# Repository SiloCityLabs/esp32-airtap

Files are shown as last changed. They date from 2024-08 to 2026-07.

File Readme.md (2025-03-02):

# AC Infinity ESP32 Mods



This repository contains code and instructions to modify the AC Infinity products with an ESP32 microcontroller. The ESP32 is a powerful microcontroller that can be used to control the fan speed, monitor temperature and humidity, and connect to the internet. The modifications described in this repository will allow you to control your fan remotely, set up schedules, and monitor environmental conditions in your grow room or other indoor space.

Get it on [SiloCityLabs Shop](https://shop.silocitylabs.com/products/esp32-module-for-ac-infinity-airtap-t4-t6)

 ## Airtap T-Series ESP32 Mods

Code and instructions to modify the AC Infinity Airtap T-Series inline duct fans with an ESP32 microcontroller.

**Youtube Video:** [Shorts](https://www.youtube.com/shorts/T40RKEEfJKI)

 - Disassembly: Carefully open your AC Infinity vent to access the original PCB.
 - Compare PCB Layout: Match your vent’s PCB layout with the images provided to ensure compatibility with one of the three supported versions.
 - Upload Firmware: Use the provided ESPHome configuration links to upload the correct firmware version to your ESP32 module or alternative firmware compatible with ESP32-c3 module.
 - Install the ESP32 Module:
 - Replace the existing PCB with the ESP32 module.
 - Connect the PWM fans and NTC thermistor to the corresponding terminals on the new PCB.
 - (If needed) Solder the power cable to the correct pads on the PCB.
 - Secure the Module: Reassemble the vent, ensuring that all connections are secure and the module is properly seated.
 - Test Functionality: Power on the vent and check that the display is working and the device connects to your Wi-Fi network.

### How to identify your Generation

3 buttons is Gen 1, 4 buttons is Gen 2.

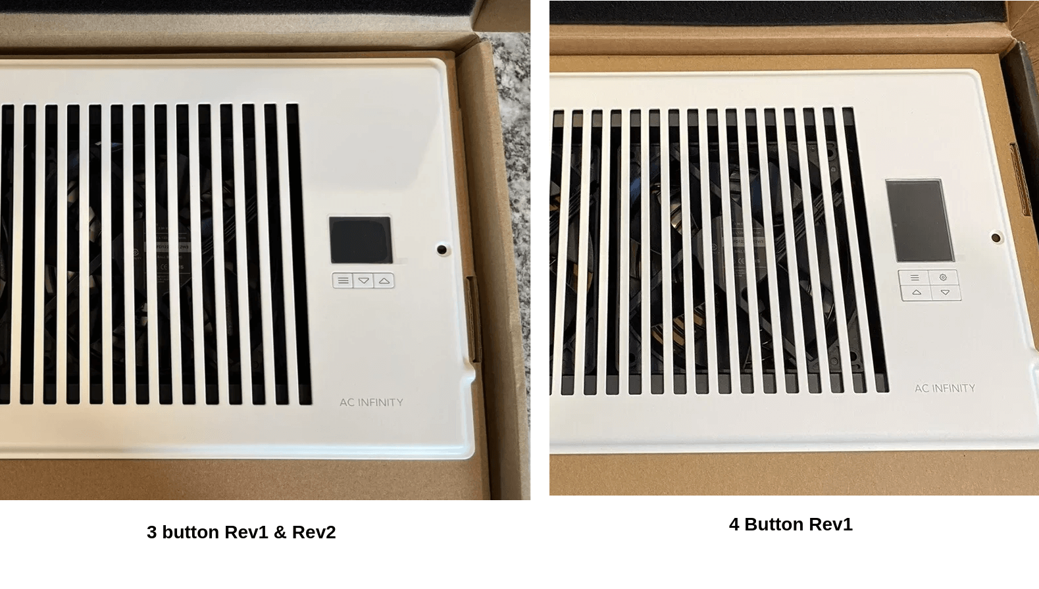
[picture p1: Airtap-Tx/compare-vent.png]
Vent Comparison


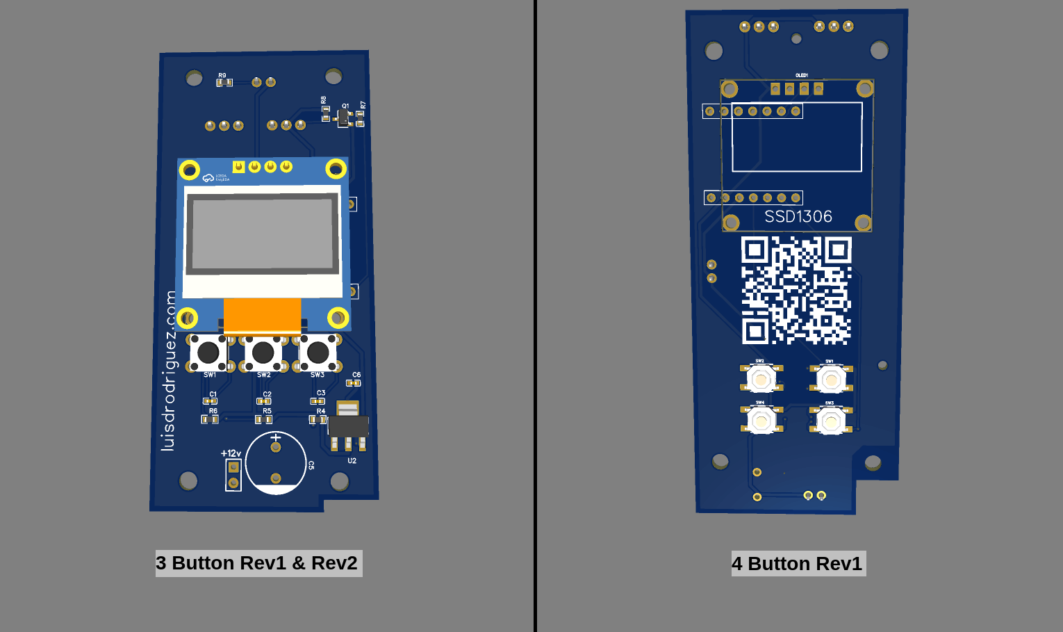
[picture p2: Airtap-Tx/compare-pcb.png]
PCB Comparison


### Gen 1 Rev 1

This revision of Gen 1 has an aligment issue. When installed you should only use two left screws to secure the PCB. The right screws will not align with the holes. Also includes individual fan control with two PWM outputs.

[ESPHome Configuration](Airtap-Tx/Gen-1/esphome-3btn-rev1.yaml)

This includes a font that needs to be downloaded and placed in the same directory as your configuration file. You can download the font file [here](https://font.download/font/arial)

#### Pinout:

| ESP32 Pin | Function | Xiao Pin |
|---|---|---|
| GPIO2 | PWM | D0 |
| GPIO3 | PWM | D1 |
| GPIO4 | Temp | D3 |
| GPIO6 | OLED SDA | D4 |
| GPIO7 | OLED SCL | D5 |
| GPIO8 | Button Up | D8 |
| GPIO9 | Button Down | D9 |
| GPIO10 | Button Toggle | D10 |

#### Features
 - 2x PWM Output
 - 1x Temperature Sensor
 - 1x Display
 - 3x Button

### Gen 1 Rev 2

This is the second revision of Gen 1. It has the same layout with fixed hole aligment. The second PWM output was removed and both fans are controlled from a single PWM output.

[ESPHome Configuration](Airtap-Tx/Gen-1/esphome-3btn-rev2.yaml)

This includes a font that needs to be downloaded and placed in the same directory as your configuration file. You can download the font file [here](https://font.download/font/arial)

#### Features
 - 1x PWM Output
 - 1x Temperature Sensor
 - 1x Display
 - 3x Button

#### Pinout:

| ESP32 Pin | Function | Xiao Pin |
|---|---|---|
| GPIO2 | PWM | D0 |
| GPIO4 | Temp | D3 |
| GPIO6 | OLED SDA | D4 |
| GPIO7 | OLED SCL | D5 |
| GPIO8 | Button Up | D8 |
| GPIO9 | Button Down | D9 |
| GPIO10 | Button Toggle | D10 |

### Gen 2 Rev 1

This is the second Generation of Airtap series. AC Infinity introduced a larger display, 4 buttons, bluetooth and a new PCB layout. This revision has a single PWM output and a temperature sensor.

[ESPHome Configuration](Airtap-Tx/Gen-2/esphome-4btn-rev1.yaml)

#### Features
 - 1x PWM Output
 - 1x Temperature Sensor
 - 1x Display
 - 4x Button

#### Pinout:

| ESP32 Pin | Function | Xiao Pin |
|---|---|---|
| GPIO2 | PWM | D0 |
| GPIO4 | Temp | D3 |
| GPIO6 | OLED SDA | D4 |
| GPIO7 | OLED SCL | D5 |
| GPIO20 | Button Up | D7 |
| GPIO8 | Button Down | D8 |
| GPIO9 | Button Toggle | D9 |
| GPIO10 | Button Menu | D10 |

 ## Availability
You can get the assembled boards in my [Shop](https://shop.silocitylabs.com/products/esp32-module-for-ac-infinity-airtap-t4-t6)

## Certifications

This project is certified by the [Open Source Hardware Association (OSHWA)](https://certification.oshwa.org/us002672.html)

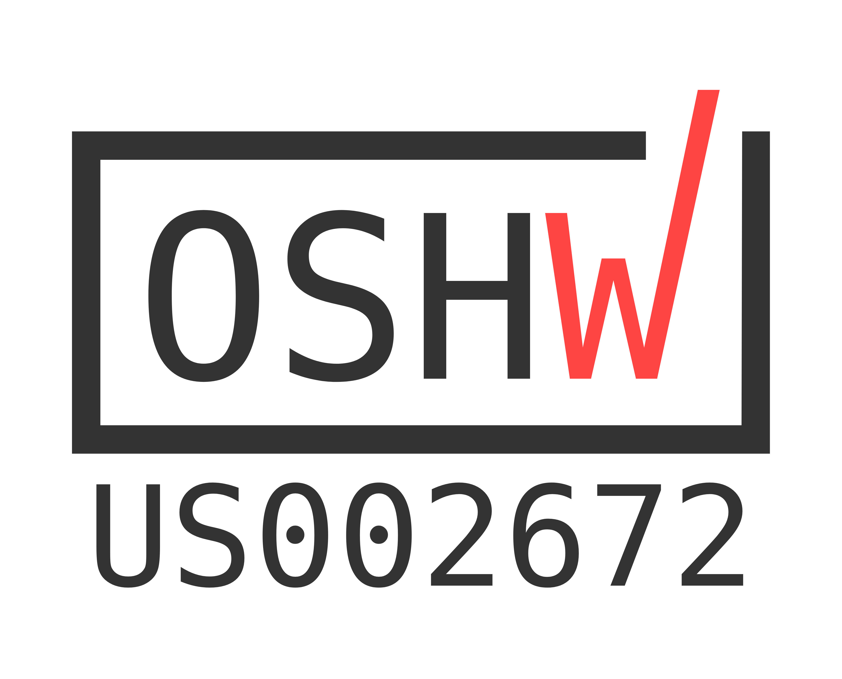
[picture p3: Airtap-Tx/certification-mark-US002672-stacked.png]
Open Source Hardware Association Certification


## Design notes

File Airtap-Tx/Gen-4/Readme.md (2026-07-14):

This is a new Airtap by AC Infinity. Reverse engineering notes here:

Header Pads exposed:
 - IO9 (BOOT / download strap — hold LOW + pulse EN to enter ROM bootloader)
 - GND
 - TX
 - RX
 - 3.3V
 - EN

Chip: ESP32-C6-WROOM-1
UART console: 115200 8N1 on TX/RX header

OEM boot log (normal SPI boot):
- Project: smarthome_device_airtap v2.1 (ESP-IDF v5.4.1, Apr 9 2026 20:33:54)
- Versions reported: hw 3.0 / sw 3.0.15
- Secure boot: RSA-PSS enabled (verification succeeded)
- Flash encryption: DEVELOPMENT (not secure)
- Power-on path: BLE / Blufi provisioning
- MAC seen: a0:f2:62:71:bc:e4
- Input GPIOs (pull-up): 5, 6, 7, 21, 22
- Output GPIOs: 8, 10, 11, 15, 18, 19, 23, 20, 1, 4

Download mode (UART dump/flash):
1. Hold IO9 to GND
2. Pulse EN low then high
3. Release IO9
4. esptool --port /dev/ttyUSB0 --chip esp32c6 --before no-reset --after no-reset ...
   Use baud <= 460800 on this CH340; 921600 corrupts the link.

Flash dump:
- oem-firmware-full.bin — full 8MB SPI dump (ciphertext; flash encryption enabled)
- SHA256: ff35eccd4f6936a8b0c3f98f9bc9d93c65edfefdc661ccb78f1077a39ab8743d
- oem-partition-table.bin — 0x8000..0x8C00 (also ciphertext)
- oem-security-info.txt / oem-efuse-summary.txt
- Flash size: 8MB (GD/c8 4017)
- SPI_BOOT_CRYPT_CNT=0b111 (encryption permanently on)
- RD_DIS blocks reading KEY0/KEY1 (flash encrypt key not readable via espefuse)
- Secure boot digests present; JTAG permanently disabled; DIS_DOWNLOAD_ICACHE=1
- DIS_DOWNLOAD_MANUAL_ENCRYPT=0 (download-mode encrypt still allowed)

Manual Pin traces:

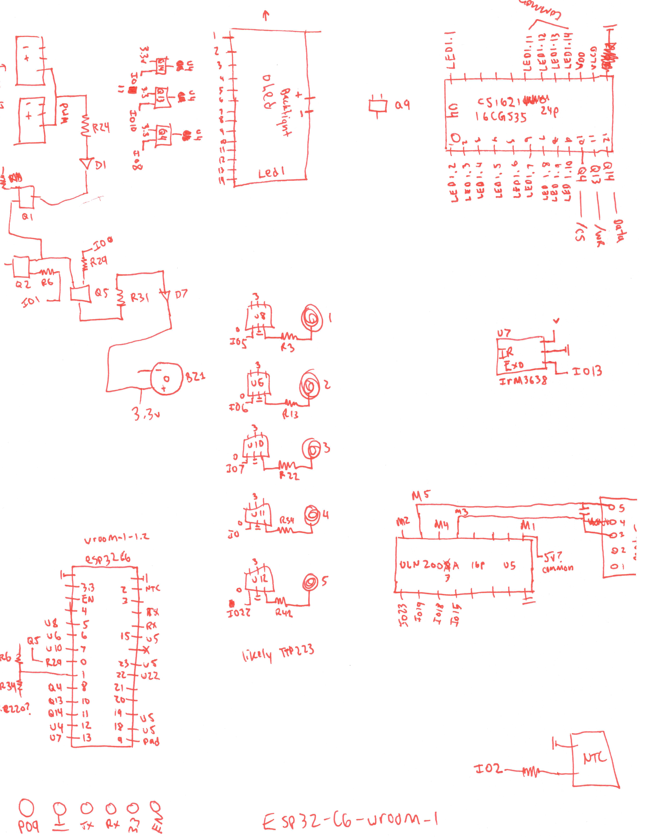
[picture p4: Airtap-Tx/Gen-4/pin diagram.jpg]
Pin diagram


| GPIO | Chip / target | Notes |
| --- | --- | --- |
| IO0 | Piezo (BZ1) via Q5 | R29 → Q5; likely buzzer drive |
| IO1 | Fan PWM / power via Q2 | R6/R34 → Q2; PWM path TBD vs Q1 |
| IO2 | NTC | ADC / temp sense |
| IO3 | — | Untraced |
| IO4 | — | Untraced |
| IO5 | TTP223 (U8) | Touch 1 |
| IO6 | TTP223 (U6) | Touch 2 |
| IO7 | TTP223 (U10) | Touch 3 |
| IO8 | CS1621 via Q4 | `/CS` |
| IO9 | Header pad | BOOT / download strap |
| IO10 | CS1621 via Q13 | `/WR` |
| IO11 | CS1621 via Q14 | `DATA` |
| IO12 | — | Untraced |
| IO13 | IRM3638 | IR receiver |
| IO15 | ULN2003A | Motor pin 4 |
| IO18 | ULN2003A | Motor pin 3 |
| IO19 | ULN2003A | Motor pin 2 |
| IO20 | — | Untraced (backlight candidate?) |
| IO21 | TTP223 | Touch 4 (hard to probe; firmware input) |
| IO22 | TTP223 (U12) | Touch 5 |
| IO23 | ULN2003A | Motor pin 1 |

Still missing pin matching:

PWM Control, Likely one of Q1, Q2 or Q5 Transistors
Piezzo Likely Q2 or Q5 transistors
Backlight?

CS1621:

| Pin | Signal |
| --- | --- |
| 1 | LED 1.2 |
| 2 | LED 1.3 |
| 3 | LED 1.4 |
| 4 | LED 1.5 |
| 5 | LED 1.6 |
| 6 | LED 1.7 |
| 7 | LED 1.8 |
| 8 | LED 1.9 |
| 9 | LED 1.10 |
| 10 | /CS |
| 11 | /WR |
| 12 | DATA |
| 13 | GND |
| 14 | VLCD ? |
| 15 | VDD |
| 16 | LED 1.14 |
| 17 | LED 1.13 |
| 18 | LED 1.12 |
| 19 | LED 1.11 |
| 20 | NC |
| 21 | NC |
| 22 | NC |
| 23 | NC |
| 24 | LED 1.1 |

Serial log confirmation (2026-07-13 capture → serial-logs/latest.log):
GPIO init vs traces:
- Confirmed inputs (pull-up): IO5/6/7/21/22 → matches TTP223 on 5/6/7/22; IO21 still unknown but is a 5th touch/key input in firmware
- Confirmed outputs: IO8/10/11 → matches CS1621 /CS /WR DATA
- Confirmed outputs: IO15/18/19/23 → matches ULN2003A motor pins
- IO2: neither in nor out (ADC-style) + Curve Fitting calibration immediately after → supports NTC on IO2
- Confirmed outputs still ambiguous: IO1, IO4, IO20 (buzzer / PWM / backlight candidates)
- IO0 never appears in gpio init log (may still be buzzer path, just not logged here)
- RMT RX channel enabled → supports IR RX (IRM3638 / IO13); pin number not printed
Runtime interaction in same capture:
- ct_ir_manage power 0→1 (IR remote power)
- Key_Func "Up Key" twice → ipcd_set_speed 2 then 3

Custom firmware / pinprobe:
- esphome-pinprobe.yaml cycles GPIO0(PWM) / 1(2kHz) / 4(4kHz) / 20 / 3 / 12
- FLASHED 2026-07-13 with --encrypt: write succeeded, boot FAILED
  - "Image not V2 signed?" / "RSA-PSS secure boot verification failed" bootloop
- OEM restored via firmware-dump/oem-firmware-full.bin (hash verified)
- End-goal ESPHome on THIS module is blocked without AC Infinity signing key
- Path forward: replace ESP32-C6-WROOM-1 with an unlocked module, then flash ESPHome

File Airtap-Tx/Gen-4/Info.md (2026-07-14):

This is a new Airtap by AC Infinity. Reverse engineering notes here:

Header Pads exposed:
 - IO9 (BOOT / download strap — hold LOW + pulse EN to enter ROM bootloader)
 - GND
 - TX
 - RX
 - 3.3V
 - EN

Chip: ESP32-C6-WROOM-1
UART console: 115200 8N1 on TX/RX header

OEM boot log (normal SPI boot):
- Project: smarthome_device_airtap v2.1 (ESP-IDF v5.4.1, Apr 9 2026 20:33:54)
- Versions reported: hw 3.0 / sw 3.0.15
- Secure boot: RSA-PSS enabled (verification succeeded)
- Flash encryption: DEVELOPMENT (not secure)
- Power-on path: BLE / Blufi provisioning
- MAC seen: a0:f2:62:71:bc:e4
- Input GPIOs (pull-up): 5, 6, 7, 21, 22
- Output GPIOs: 8, 10, 11, 15, 18, 19, 23, 20, 1, 4

Download mode (UART dump/flash):
1. Hold IO9 to GND
2. Pulse EN low then high
3. Release IO9
4. esptool --port /dev/ttyUSB0 --chip esp32c6 --before no-reset --after no-reset ...
   Use baud <= 460800 on this CH340; 921600 corrupts the link.

Flash dump:
- oem-firmware-full.bin — full 8MB SPI dump (ciphertext; flash encryption enabled)
- SHA256: ff35eccd4f6936a8b0c3f98f9bc9d93c65edfefdc661ccb78f1077a39ab8743d
- oem-partition-table.bin — 0x8000..0x8C00 (also ciphertext)
- oem-security-info.txt / oem-efuse-summary.txt
- Flash size: 8MB (GD/c8 4017)
- SPI_BOOT_CRYPT_CNT=0b111 (encryption permanently on)
- RD_DIS blocks reading KEY0/KEY1 (flash encrypt key not readable via espefuse)
- Secure boot digests present; JTAG permanently disabled; DIS_DOWNLOAD_ICACHE=1
- DIS_DOWNLOAD_MANUAL_ENCRYPT=0 (download-mode encrypt still allowed)

Manual Pin traces:

IO0 - R29 -> Q5 -> ?? Maybe Buzzer
IO1 - R6/R34 -> ??
IO2 - NTC
IO3 - ??
IO4 - ??
IO5 - TTP223 TOUCH 1
IO6 - TTP223 TOUCH 2
IO7 - TTP223 TOUCH 3
IO8 - Q4(Transistor) -> CS1621(/CS)
IO9 - PAD9
IO10 - Q13(Transistor) -> CS1621(/WR)
IO11 - Q14(Transistor) -> CS1621(DATA)
IO12 - ??
IO13 - IRM3638 IR
IO15 - Motor Pin 4 (ULN2003A)
IO18 - Motor Pin 3 (ULN2003A)
IO19 - Motor Pin 2 (ULN2003A)
IO20 - ??
IO21 - TTP223 TOUCH 4
IO22 - TTP223 TOUCH 5
IO23 - Motor Pin 1 (ULN2003A)

Still missing pin matching:

PWM Control, Likely one of Q1, Q2 or Q5 Transistors
Piezzo Likely Q2 or Q5 transistors
Backlight?

CS1621:

1 - LED 1.2
2 - LED 1.3
3 - LED 1.4
4 - LED 1.5
5 - LED 1.6
6 - LED 1.7
7 - LED 1.8
8 - LED 1.9
9 - LED 1.10
10 - /CS
11 - /WR
12 - DATA
13 - GND
14 - VLCD ?
15 - VDD
16 - LED 1.14
17 - LED 1.13
18 - LED 1.12
19 - LED 1.11
20 - NC
21 - NC
22 - NC
23 - NC
24 - LED 1.1

Serial log confirmation (2026-07-13 capture → serial-logs/latest.log):
GPIO init vs traces:
- Confirmed inputs (pull-up): IO5/6/7/21/22 → matches TTP223 on 5/6/7/22; IO21 still unknown but is a 5th touch/key input in firmware
- Confirmed outputs: IO8/10/11 → matches CS1621 /CS /WR DATA
- Confirmed outputs: IO15/18/19/23 → matches ULN2003A motor pins
- IO2: neither in nor out (ADC-style) + Curve Fitting calibration immediately after → supports NTC on IO2
- Confirmed outputs still ambiguous: IO1, IO4, IO20 (buzzer / PWM / backlight candidates)
- IO0 never appears in gpio init log (may still be buzzer path, just not logged here)
- RMT RX channel enabled → supports IR RX (IRM3638 / IO13); pin number not printed
Runtime interaction in same capture:
- ct_ir_manage power 0→1 (IR remote power)
- Key_Func "Up Key" twice → ipcd_set_speed 2 then 3

Custom firmware / pinprobe:
- esphome-pinprobe.yaml cycles GPIO0(PWM) / 1(2kHz) / 4(4kHz) / 20 / 3 / 12
- FLASHED 2026-07-13 with --encrypt: write succeeded, boot FAILED
  - "Image not V2 signed?" / "RSA-PSS secure boot verification failed" bootloop
- OEM restored via firmware-dump/oem-firmware-full.bin (hash verified)
- End-goal ESPHome on THIS module is blocked without AC Infinity signing key
- Path forward: replace ESP32-C6-WROOM-1 with an unlocked module, then flash ESPHome

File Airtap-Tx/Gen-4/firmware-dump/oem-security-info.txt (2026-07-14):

esptool v5.2.0
Serial port /dev/ttyUSB0:
Note: Pre-connection option "no-reset" was selected. Connection may fail if the chip is not in bootloader or flasher stub mode.
Connecting....
Connected to ESP32-C6 on /dev/ttyUSB0:
Chip type:          ESP32-C6 (QFN40) (revision v0.2)
Features:           Wi-Fi 6, BT 5 (LE), IEEE802.15.4, Single Core + LP Core, 160MHz, Unknown Embedded Flash
Crystal frequency:  40MHz
MAC:                a0:f2:62:ff:fe:71:bc:e4
BASE MAC:           a0:f2:62:71:bc:e4
MAC_EXT:            ff:fe

Uploading stub flasher...
Running stub flasher...
Stub flasher running.

Security Information:
=====================
Flags: 0x000004f1 (0b10011110001)
Key Purposes: (8, 4, 9, 0, 0, 0, 12)
  BLOCK_KEY0 - HMAC_UP
  BLOCK_KEY1 - XTS_AES_128_KEY
  BLOCK_KEY2 - SECURE_BOOT_DIGEST0
  BLOCK_KEY3 - USER/EMPTY
  BLOCK_KEY4 - USER/EMPTY
  BLOCK_KEY5 - USER/EMPTY
Chip ID: 13
API Version: 0
Secure Boot: Enabled
Secure Boot Key Revocation Status:

	Secure Boot Key1 is Revoked

	Secure Boot Key2 is Revoked

Flash Encryption: Enabled
SPI Boot Crypt Count (SPI_BOOT_CRYPT_CNT): 0x7
Icache in UART download mode: Disabled
JTAG: Permanently Disabled

Staying in bootloader.
esptool v5.2.0
Serial port /dev/ttyUSB0:
Note: Pre-connection option "no-reset" was selected. Connection may fail if the chip is not in bootloader or flasher stub mode.
Connecting....
Connected to ESP32-C6 on /dev/ttyUSB0:
Chip type:          ESP32-C6 (QFN40) (revision v0.2)
Features:           Wi-Fi 6, BT 5 (LE), IEEE802.15.4, Single Core + LP Core, 160MHz, Unknown Embedded Flash
Crystal frequency:  40MHz
MAC:                a0:f2:62:ff:fe:71:bc:e4
BASE MAC:           a0:f2:62:71:bc:e4
MAC_EXT:            ff:fe

Uploading stub flasher...
Running stub flasher...
Stub flasher running.

Flash Memory Information:
=========================
Manufacturer: c8
Device: 4017
Detected flash size: 8MB

Staying in bootloader.

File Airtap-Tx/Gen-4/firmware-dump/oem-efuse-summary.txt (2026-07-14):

espefuse v5.2.0
Note: Pre-connection option "no-reset" was selected. Connection may fail if the chip is not in bootloader or flasher stub mode.
Connecting....

=== Run "summary" command ===
EFUSE_NAME (Block) Description  = [Meaningful Value] [Readable/Writeable] (Hex Value)
----------------------------------------------------------------------------------------
Calibration fuses:
ACTIVE_HP_DBIAS (BLOCK1)                           Stores the active hp dbias                         = -28 R/W (0b10111)
ACTIVE_LP_DBIAS (BLOCK1)                           Stores the active lp dbias                         = -32 R/W (0b11000)
LSLP_HP_DBG (BLOCK1)                               Stores the lslp hp dbg                             = 1 R/W (0b01)
LSLP_HP_DBIAS (BLOCK1)                             Stores the lslp hp dbias                           = 0 R/W (0x0)
DSLP_LP_DBG (BLOCK1)                               Stores the dslp lp dbg                             = 7 R/W (0b111)
DSLP_LP_DBIAS (BLOCK1)                             Stores the dslp lp dbias                           = 12 R/W (0x3)
DBIAS_VOL_GAP (BLOCK1)                             Stores the hp and lp dbias vol gap                 = 4 R/W (0b00001)
TEMP_CALIB (BLOCK2)                                Temperature calibration data                       = -12.4 R/W (0b101111100)
OCODE (BLOCK2)                                     ADC OCode                                          = 94 R/W (0x5e)
ADC1_INIT_CODE_ATTEN0 (BLOCK2)                     ADC1 init code at atten0                           = -204 R/W (0b1000110011)
ADC1_INIT_CODE_ATTEN1 (BLOCK2)                     ADC1 init code at atten1                           = -232 R/W (0b1000111010)
ADC1_INIT_CODE_ATTEN2 (BLOCK2)                     ADC1 init code at atten2                           = -236 R/W (0b1000111011)
ADC1_INIT_CODE_ATTEN3 (BLOCK2)                     ADC1 init code at atten3                           = -264 R/W (0b1001000010)
ADC1_CAL_VOL_ATTEN0 (BLOCK2)                       ADC1 calibration voltage at atten0                 = -172 R/W (0b1000101011)
ADC1_CAL_VOL_ATTEN1 (BLOCK2)                       ADC1 calibration voltage at atten1                 = -92 R/W (0b1000010111)
ADC1_CAL_VOL_ATTEN2 (BLOCK2)                       ADC1 calibration voltage at atten2                 = -84 R/W (0b1000010101)
ADC1_CAL_VOL_ATTEN3 (BLOCK2)                       ADC1 calibration voltage at atten3                 = -172 R/W (0b1000101011)
ADC1_INIT_CODE_ATTEN0_CH0 (BLOCK2)                 ADC1 init code at atten0 ch0                       = 0 R/W (0x8)
ADC1_INIT_CODE_ATTEN0_CH1 (BLOCK2)                 ADC1 init code at atten0 ch1                       = 0 R/W (0x8)
ADC1_INIT_CODE_ATTEN0_CH2 (BLOCK2)                 ADC1 init code at atten0 ch2                       = 0 R/W (0x8)
ADC1_INIT_CODE_ATTEN0_CH3 (BLOCK2)                 ADC1 init code at atten0 ch3                       = 0 R/W (0x8)
ADC1_INIT_CODE_ATTEN0_CH4 (BLOCK2)                 ADC1 init code at atten0 ch4                       = 0 R/W (0x8)
ADC1_INIT_CODE_ATTEN0_CH5 (BLOCK2)                 ADC1 init code at atten0 ch5                       = 0 R/W (0x8)
ADC1_INIT_CODE_ATTEN0_CH6 (BLOCK2)                 ADC1 init code at atten0 ch6                       = 0 R/W (0x8)

Config fuses:
WR_DIS (BLOCK0)                                    Disable programming of individual eFuses           = 58722048 R/W (0x03800700)
RD_DIS (BLOCK0)                                    Disable reading from BlOCK4-10                     = 3 R/W (0b0000011)
SWAP_UART_SDIO_EN (BLOCK0)                         Represents whether pad of uart and sdio is swapped = False R/W (0b0)
                                                    or not. 1: swapped. 0: not swapped               
DIS_ICACHE (BLOCK0)                                Represents whether icache is disabled or enabled.  = False R/W (0b0)
                                                   1: disabled. 0: enabled                           
DIS_TWAI (BLOCK0)                                  Represents whether TWAI function is disabled or en = False R/W (0b0)
                                                   abled. 1: disabled. 0: enabled                    
DIS_DIRECT_BOOT (BLOCK0)                           Represents whether direct boot mode is disabled or = True R/W (0b1)
                                                    enabled. 1: disabled. 0: enabled                 
UART_PRINT_CONTROL (BLOCK0)                        Set the default UARTboot message output mode       = Enable R/W (0b00)
BLOCK_USR_DATA (BLOCK3)                            User data                                         
   = 00 00 00 00 00 00 00 00 00 00 00 00 00 00 00 00 00 00 00 00 00 00 00 00 00 00 00 00 00 00 00 00 R/W 
BLOCK_SYS_DATA2 (BLOCK10)                          System data part 2 (reserved)                     
   = 00 00 00 00 00 00 00 00 00 00 00 00 00 00 00 00 00 00 00 00 00 00 00 00 00 00 00 00 00 00 00 00 R/W 

Flash fuses:
FLASH_TPUW (BLOCK0)                                Represents the flash waiting time after power-up;  = 0 R/W (0x0)
                                                   in unit of ms. When the value less than 15; the wa
                                                   iting time is the programmed value. Otherwise; the
                                                    waiting time is 2 times the programmed value     
FORCE_SEND_RESUME (BLOCK0)                         Represents whether ROM code is forced to send a re = False R/W (0b0)
                                                   sume command during SPI boot. 1: forced. 0:not for
                                                   ced                                               
FLASH_CAP (BLOCK1)                                                                                    = 0 R/W (0b000)
FLASH_TEMP (BLOCK1)                                                                                   = 0 R/W (0b00)
FLASH_VENDOR (BLOCK1)                                                                                 = 0 R/W (0b000)

Identity fuses:
DISABLE_WAFER_VERSION_MAJOR (BLOCK0)               Disables check of wafer version major              = False R/W (0b0)
DISABLE_BLK_VERSION_MAJOR (BLOCK0)                 Disables check of blk version major                = False R/W (0b0)
WAFER_VERSION_MINOR (BLOCK1)                                                                          = 2 R/W (0x2)
WAFER_VERSION_MAJOR (BLOCK1)                                                                          = 0 R/W (0b00)
PKG_VERSION (BLOCK1)                               Package version                                    = 0 R/W (0b000)
BLK_VERSION_MINOR (BLOCK1)                         BLK_VERSION_MINOR of BLOCK2                        = 3 R/W (0b011)
BLK_VERSION_MAJOR (BLOCK1)                         BLK_VERSION_MAJOR of BLOCK2                        = 0 R/W (0b00)
OPTIONAL_UNIQUE_ID (BLOCK2)                        Optional unique 128-bit ID                        
   = 63 10 2d 4d 41 24 99 f5 2d df c1 9d 3a b7 f0 0a R/W 

Jtag fuses:
JTAG_SEL_ENABLE (BLOCK0)                           Represents whether the selection between usb_to_jt = False R/W (0b0)
                                                   ag and pad_to_jtag through strapping gpio15 when b
                                                   oth EFUSE_DIS_PAD_JTAG and EFUSE_DIS_USB_JTAG are 
                                                   equal to 0 is enabled or disabled. 1: enabled. 0: 
                                                   disabled                                          
SOFT_DIS_JTAG (BLOCK0)                             Represents whether JTAG is disabled in soft way. O = 7 R/W (0b111)
                                                   dd number: disabled. Even number: enabled         
DIS_PAD_JTAG (BLOCK0)                              Represents whether JTAG is disabled in the hard wa = True R/W (0b1)
                                                   y(permanently). 1: disabled. 0: enabled           

Mac fuses:
MAC (BLOCK1)                                       MAC address                                       
   = a0:f2:62:71:bc:e4 (OK) R/W 
MAC_EXT (BLOCK1)                                   Stores the extended bits of MAC address            = ff:fe (OK) R/W 
CUSTOM_MAC (BLOCK3)                                Custom MAC                                        
   = 00:00:00:00:00:00 (OK) R/W 
MAC_EUI64 (BLOCK1)                                 calc MAC_EUI64 = MAC[0]:MAC[1]:MAC[2]:MAC_EXT[0]:M
   = a0:f2:62:ff:fe:71:bc:e4 (OK) R/W 
                                                   AC_EXT[1]:MAC[3]:MAC[4]:MAC[5]                    

Security fuses:
DIS_DOWNLOAD_ICACHE (BLOCK0)                       Represents whether icache is disabled or enabled i = True R/W (0b1)
                                                   n Download mode. 1: disabled. 0: enabled          
DIS_FORCE_DOWNLOAD (BLOCK0)                        Represents whether the function that forces chip i = False R/W (0b0)
                                                   nto download mode is disabled or enabled. 1: disab
                                                   led. 0: enabled                                   
SPI_DOWNLOAD_MSPI_DIS (BLOCK0)                     Represents whether SPI0 controller during boot_mod = False R/W (0b0)
                                                   e_download is disabled or enabled. 1: disabled. 0:
                                                    enabled                                          
DIS_DOWNLOAD_MANUAL_ENCRYPT (BLOCK0)               Represents whether flash encrypt function is disab = False R/W (0b0)
                                                   led or enabled(except in SPI boot mode). 1: disabl
                                                   ed. 0: enabled                                    
SPI_BOOT_CRYPT_CNT (BLOCK0)                        Enables flash encryption when 1 or 3 bits are set  = Enable R/W (0b111)
                                                   and disables otherwise                            
SECURE_BOOT_KEY_REVOKE0 (BLOCK0)                   Revoke 1st secure boot key                         = False R/W (0b0)
SECURE_BOOT_KEY_REVOKE1 (BLOCK0)                   Revoke 2nd secure boot key                         = True R/W (0b1)
SECURE_BOOT_KEY_REVOKE2 (BLOCK0)                   Revoke 3rd secure boot key                         = True R/W (0b1)
KEY_PURPOSE_0 (BLOCK0)                             Represents the purpose of Key0                     = HMAC_UP R/- (0x8)
KEY_PURPOSE_1 (BLOCK0)                             Represents the purpose of Key1                     = XTS_AES_128_KEY R/- (0x4)
KEY_PURPOSE_2 (BLOCK0)                             Represents the purpose of Key2                     = SECURE_BOOT_DIGEST0 R/- (0x9)
KEY_PURPOSE_3 (BLOCK0)                             Represents the purpose of Key3                     = USER R/W (0x0)
KEY_PURPOSE_4 (BLOCK0)                             Represents the purpose of Key4                     = USER R/W (0x0)
KEY_PURPOSE_5 (BLOCK0)                             Represents the purpose of Key5                     = USER R/W (0x0)
SEC_DPA_LEVEL (BLOCK0)                             Represents the spa secure level by configuring the = 0 R/W (0b00)
                                                    clock random divide mode                         
CRYPT_DPA_ENABLE (BLOCK0)                          Represents whether anti-dpa attack is enabled. 1:e = False R/W (0b0)
                                                   nabled. 0: disabled                               
SECURE_BOOT_EN (BLOCK0)                            Represents whether secure boot is enabled or disab = True R/W (0b1)
                                                   led. 1: enabled. 0: disabled                      
SECURE_BOOT_AGGRESSIVE_REVOKE (BLOCK0)             Represents whether revoking aggressive secure boot = False R/W (0b0)
                                                    is enabled or disabled. 1: enabled. 0: disabled  
DIS_DOWNLOAD_MODE (BLOCK0)                         Represents whether Download mode is disabled or en = False R/W (0b0)
                                                   abled. 1: disabled. 0: enabled                    
ENABLE_SECURITY_DOWNLOAD (BLOCK0)                  Represents whether security download is enabled or = False R/W (0b0)
                                                    disabled. 1: enabled. 0: disabled                
SECURE_VERSION (BLOCK0)                            Represents the version used by ESP-IDF anti-rollba = 0 R/W (0x0000)
                                                   ck feature                                        
SECURE_BOOT_DISABLE_FAST_WAKE (BLOCK0)             Represents whether FAST VERIFY ON WAKE is disabled = False R/W (0b0)
                                                    or enabled when Secure Boot is enabled. 1: disabl
                                                   ed. 0: enabled                                    
BLOCK_KEY0 (BLOCK4)
  Purpose: HMAC_UP
            Key0 or user data                                 
   = ?? ?? ?? ?? ?? ?? ?? ?? ?? ?? ?? ?? ?? ?? ?? ?? ?? ?? ?? ?? ?? ?? ?? ?? ?? ?? ?? ?? ?? ?? ?? ?? -/- 
BLOCK_KEY1 (BLOCK5)
  Purpose: XTS_AES_128_KEY
    Key1 or user data                                 
   = ?? ?? ?? ?? ?? ?? ?? ?? ?? ?? ?? ?? ?? ?? ?? ?? ?? ?? ?? ?? ?? ?? ?? ?? ?? ?? ?? ?? ?? ?? ?? ?? -/- 
BLOCK_KEY2 (BLOCK6)
  Purpose: SECURE_BOOT_DIGEST0
  Key2 or user data                                 
   = 26 d7 af e3 0a 82 48 75 17 23 a9 09 68 65 45 e4 1f 85 d9 98 cd 10 fd 24 2f 90 73 28 00 dd 9e e6 R/- 
BLOCK_KEY3 (BLOCK7)
  Purpose: USER
               Key3 or user data                                 
   = 00 00 00 00 00 00 00 00 00 00 00 00 00 00 00 00 00 00 00 00 00 00 00 00 00 00 00 00 00 00 00 00 R/W 
BLOCK_KEY4 (BLOCK8)
  Purpose: USER
               Key4 or user data                                 
   = 00 00 00 00 00 00 00 00 00 00 00 00 00 00 00 00 00 00 00 00 00 00 00 00 00 00 00 00 00 00 00 00 R/W 
BLOCK_KEY5 (BLOCK9)
  Purpose: USER
               Key5 or user data                                 
   = 00 00 00 00 00 00 00 00 00 00 00 00 00 00 00 00 00 00 00 00 00 00 00 00 00 00 00 00 00 00 00 00 R/W 

Usb fuses:
DIS_USB_JTAG (BLOCK0)                              Represents whether the function of usb switch to j = True R/W (0b1)
                                                   tag is disabled or enabled. 1: disabled. 0: enable
                                                   d                                                 
DIS_USB_SERIAL_JTAG (BLOCK0)                       Represents whether USB-Serial-JTAG is disabled or  = False R/W (0b0)
                                                   enabled. 1: disabled. 0: enabled                  
USB_EXCHG_PINS (BLOCK0)                            Represents whether the D+ and D- pins is exchanged = False R/W (0b0)
                                                   . 1: exchanged. 0: not exchanged                  
DIS_USB_SERIAL_JTAG_ROM_PRINT (BLOCK0)             Represents whether print from USB-Serial-JTAG is d = False R/W (0b0)
                                                   isabled or enabled. 1: disabled. 0: enabled       
DIS_USB_SERIAL_JTAG_DOWNLOAD_MODE (BLOCK0)         Represents whether the USB-Serial-JTAG download fu = False R/W (0b0)
                                                   nction is disabled or enabled. 1: disabled. 0: ena
                                                   bled                                              

Vdd fuses:
VDD_SPI_AS_GPIO (BLOCK0)                           Represents whether vdd spi pin is functioned as gp = False R/W (0b0)
                                                   io. 1: functioned. 0: not functioned              

Wdt fuses:
WDT_DELAY_SEL (BLOCK0)                             Represents whether RTC watchdog timeout threshold  = 0 R/W (0b00)
                                                   is selected at startup. 1: selected. 0: not select
                                                   ed

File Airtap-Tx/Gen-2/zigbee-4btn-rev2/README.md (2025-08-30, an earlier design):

# Airtap Zigbee 4-Button PCB Replacement

A Zigbee-enabled 4-button PCB replacement for AC Infinity vent fans, built on ESP32-C6 with native IEEE 802.15.4 radio support.

## Overview

The Airtap Zigbee 4-Button PCB is a smart pcb replacement that allows wireless control of AC Infinity fan systems through Zigbee networks. The device features:

- **4 Physical Buttons**: Mode, Up, Down, and Toggle controls
- **Zigbee Connectivity**: Native IEEE 802.15.4 radio on ESP32-C6
- **Fan Speed Control**: 10-speed fan control (0-100%)
- **Temperature Monitoring**: Built-in NTC temperature sensor
- **Easy Pairing**: Simple pairing process with Zigbee hubs

## Technical Specifications

### Hardware
- **Microcontroller**: ESP32-C6 (160MHz, 320KB RAM, 8MB Flash)
- **Radio**: Native IEEE 802.15.4 (Zigbee) support
- **Buttons**: 4 tactile buttons with debouncing
- **Temperature Sensor**: NTC thermistor with ADC
- **PWM Output**: Fan speed control via PWM

### Zigbee Specifications
- **Profile**: Zigbee Home Automation (ZHA)
- **Device Type**: On/Off Light (acts as fan controller)
- **Role**: End Device (ZED)
- **Channels**: Channel 11 (2.405 GHz)
- **Security**: Standard Zigbee security
- **Network Size**: Supports up to 64 devices

### Firmware Details
- **Framework**: ESP-IDF 5.3.2
- **Zigbee SDK**: ESP Zigbee SDK
- **Build System**: PlatformIO
- **Flash Usage**: ~850KB (92.3%)
- **RAM Usage**: ~27KB (8.3%)

## Button Functions

### Normal Operation
- **MODE Button**: 
  - Short press (1-10s): Trigger pairing mode
  - Long press (10s+): Factory reset
- **TOGGLE Button**: Turn fan on/off
- **UP Button**: Increase fan speed (1-10)
- **DOWN Button**: Decrease fan speed (1-10)

### Special Functions
- **Pairing Mode**: Press MODE button for 1-10 seconds
- **Factory Reset**: Hold MODE button for 10+ seconds
- **Speed Memory**: Device remembers last non-zero speed setting

## Zigbee Pairing Instructions

### Automatic Pairing (Recommended)
1. **Power On**: Simply turn on the device
2. **Auto-Discovery**: Device automatically searches for open Zigbee networks
3. **Join Network**: Device joins the first available network
4. **Ready**: Device is ready for use (LED indicators may show status)

### Manual Pairing
1. **Prepare Hub**: Ensure your Zigbee hub is in pairing mode
2. **Trigger Pairing**: Press and hold the MODE button for 1-10 seconds
3. **Wait for Join**: Device will attempt to join the network
4. **Confirmation**: Check your hub's app for successful pairing

### Factory Reset
1. **Reset Device**: Hold MODE button for 10+ seconds
2. **Wait for Reset**: Device will leave current network
3. **Restart Pairing**: Device automatically starts pairing process
4. **Re-pair**: Follow pairing instructions above

## Integration with Zigbee Hubs

### Supported Hubs
- **Home Assistant** (untested)
- **Philips Hue Bridge** (untested)
- **Samsung SmartThings** (untested)
- **Amazon Echo Plus/Show** (untested)
- **IKEA TRÅDFRI Gateway** (untested)
- **Tuya Zigbee Gateway** (untested)
- **Hubitat** (untested)

### Device Recognition
The device appears as an **On/Off Light** in most Zigbee hubs:
- **Device Type**: On/Off Light
- **Manufacturer**: AC Infinity
- **Model**: Airtap-4BTN
- **Endpoints**: 1 (Light control)

### Control Methods
- **On/Off**: Toggle fan power
- **Level Control**: Adjust fan speed (0-10)
- **Direct Control**: Use physical buttons
- **Remote Control**: Use hub's mobile app

## Troubleshooting

### Pairing Issues
1. **Check Hub**: Ensure hub is in pairing mode
2. **Distance**: Keep device within 10-30 feet of hub
3. **Interference**: Move away from WiFi routers
4. **Reset**: Try factory reset if pairing fails
5. **Retry**: Device automatically retries pairing every 5 seconds

### Connection Issues
2. **Range**: Move device closer to hub
3. **Obstacles**: Remove metal objects between device and hub
4. **Network**: Check if hub's network is stable

### Button Not Responding
1. **Reset**: Try factory reset
3. **Physical**: Check button contacts
4. **Firmware**: Device may need firmware update

## Development Information

### Building the Firmware
```bash
# Install PlatformIO
pip install platformio

# Build for ESP32-C6
pio run -e esp32c6

# Upload to device
pio run -e esp32c6 -t upload
```

### Project Structure
```
zigbee-4btn-rev2/
├── src/
│   └── main.c              # Main application code
├── components/
│   └── esp-zigbee-sdk/     # ESP Zigbee SDK
├── platformio.ini          # PlatformIO configuration
├── CMakeLists.txt          # CMake configuration
├── partitions.csv          # Flash partition table
└── sdkconfig.defaults      # ESP-IDF configuration
```

### Key Features Implemented
- **Network Steering**: Automatic network discovery and joining
- **Factory Reset**: Complete network removal
- **Button Handling**: Debounced button input with special functions
- **Fan Control**: PWM-based speed control
- **Temperature Sensing**: ADC-based temperature monitoring
- **Error Handling**: Robust error recovery and retry logic

### Zigbee Stack Integration
- **BDB Commissioning**: Base Device Behavior for network joining
- **ZDO Signals**: Zigbee Device Object signal handling
- **ZCL Clusters**: Zigbee Cluster Library for device functionality
- **Security**: Standard Zigbee security implementation

## Support

For technical support or questions:
- **Documentation**: Check this README and code comments
- **Issues**: Report bugs through the project repository
- **Community**: Join AC Infinity user forums

---

**Note**: This device is designed for use with AC Infinity fan systems. Ensure compatibility with your specific fan model before use.

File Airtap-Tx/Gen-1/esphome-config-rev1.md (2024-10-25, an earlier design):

```yaml
esphome:
  name: my-vent
  friendly_name: My Vent

esp32:
  board: esp32-c3-devkitm-1
  framework:
    type: arduino

# Enable logging
logger:

# Enable Home Assistant API
api:
  encryption:
    key: 

ota:
  - platform: esphome
    password: 

wifi:
  ssid: !secret wifi_ssid
  password: !secret wifi_password

  # Enable fallback hotspot (captive portal) in case wifi connection fails
  ap:
    ssid: "My-Vent Fallback Hotspot"
    password: ""

captive_portal:

i2c:
  sda: GPIO6
  scl: GPIO7
  scan: True

globals:
  - id: fan_speed
    type: int
    restore_value: yes
    initial_value: '0'

button:
  - platform: restart
    icon: mdi:power-cycle
    name: "ESP Reboot"

number:
  - platform: template
    name: "Fan Speed"
    id: fan_speed_number
    min_value: 0
    max_value: 10
    step: 1
    restore_value: true
    set_action:
      - lambda: |-
          id(fan_speed) = (int)(x);
          id(fan_speed_number).publish_state(x);

sensor:
  - platform: ntc
    sensor: temp_resistance_reading
    calibration:      
      #Inversed for PTC
      - 3.389kOhm -> 0°C
      - 10.0kOhm -> 25°C
      - 27.219kOhm -> 50°C
    name: "AC Infinity Temperature"
    id: temp_sensor
    unit_of_measurement: "°C"
    accuracy_decimals: 2
    icon: "mdi:thermometer"

  - platform: resistance
    id: temp_resistance_reading
    sensor: adc_sensor
    configuration: DOWNSTREAM
    resistor: 10kOhm

  - platform: adc
    pin: GPIO4
    id: adc_sensor
    attenuation: 12db

output:
  - platform: ledc
    pin: GPIO2
    id: pwm_output_1
    frequency: 1000 Hz
    # power_supply: fan_speed

  - platform: ledc
    pin: GPIO3
    id: pwm_output_2
    frequency: 1000 Hz
    # power_supply: fan_speed

display:
  - platform: ssd1306_i2c
    model: "SSD1306 128x64"
    address: 0x3C
    # Celcius
    # lambda: |-
    #   it.printf(1, 0, id(myfont), "Airtap T-Series");
    #   it.printf(0, 14, id(myfont), "Temp: %.1f°C", id(temp_sensor).state);
    #   it.printf(0, 28, id(myfont), "Fan Speed: %d", id(fan_speed));
    # Fahrenheit
    lambda: |-
      it.printf(1, 0, id(myfont), "Airtap T-Series");
      float temp_f = (id(temp_sensor).state * 9.0 / 5.0) + 32.0;
      it.printf(0, 14, id(myfont), "Temp: %.1f°F", temp_f);
      it.printf(0, 28, id(myfont), "Fan Speed: %d", id(fan_speed));

font:
  - file: "fonts/Arial.ttf"
    id: myfont
    size: 12

binary_sensor:
  - platform: gpio
    pin: GPIO10
    name: "Mode Button"
    on_press:
      then:
        - lambda: |-
            if (id(fan_speed) == 0) {
              id(fan_speed) = 10;
            } else {
              id(fan_speed) = 0;
            }
            id(fan_speed_number).publish_state(id(fan_speed)); // Publish updated state

  - platform: gpio
    pin: GPIO8
    name: "Up Button"
    on_press:
      then:
        - lambda: |-
            if (id(fan_speed) < 10){
              id(fan_speed) += 1;
              id(fan_speed_number).publish_state(id(fan_speed)); // Publish updated state
            }

  - platform: gpio
    pin: GPIO9
    name: "Down Button"
    on_press:
      then:
        - lambda: |-
            if (id(fan_speed) > 0){
              id(fan_speed) -= 1;
              id(fan_speed_number).publish_state(id(fan_speed)); // Publish updated state
            }

light:
  - platform: monochromatic
    output: pwm_output_1
    name: "Fan 1 Speed"
    id: fan_1
    internal: true  # Hide this from Home Assistant

  - platform: monochromatic
    output: pwm_output_2
    name: "Fan 2 Speed"
    id: fan_2
    internal: true  # Hide this from Home Assistant

interval:
  - interval: 1s
    then:
      - light.turn_on:
          id: fan_1
          brightness: !lambda |-
            if (id(fan_speed) == 0) {
              return 0.0;
            } else if (id(fan_speed) == 1) {
              return 0.38;  // Minimum value to start the fan
            } else {
              return (id(fan_speed) + 3) / 13.0;
            }
      - light.turn_on:
          id: fan_2
          brightness: !lambda |-
            if (id(fan_speed) == 0) {
              return 0.0;
            } else if (id(fan_speed) == 1) {
              return 0.38;  // Minimum value to start the fan
            } else {
              return (id(fan_speed) + 3) / 13.0;
            }

```

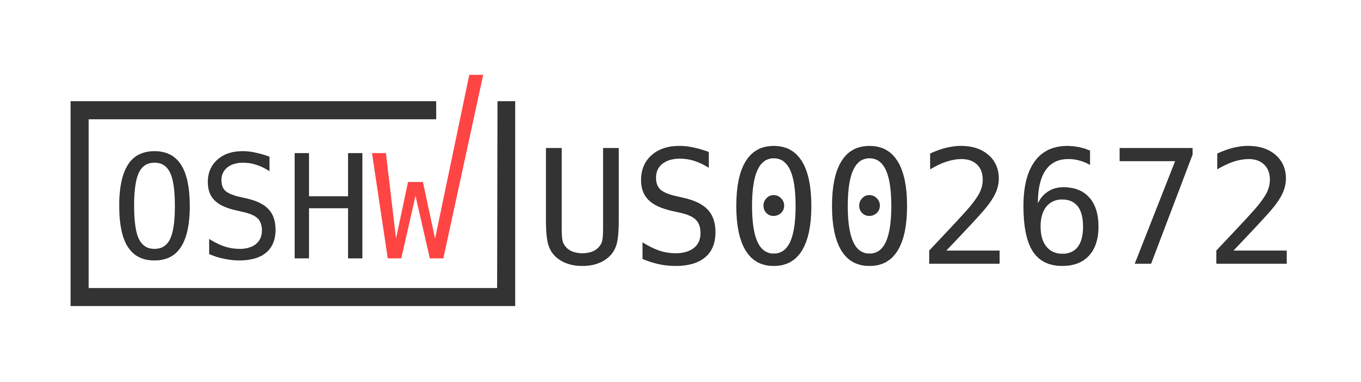
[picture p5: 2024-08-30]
Airtap-Tx/certification-mark-US002672-wide.png

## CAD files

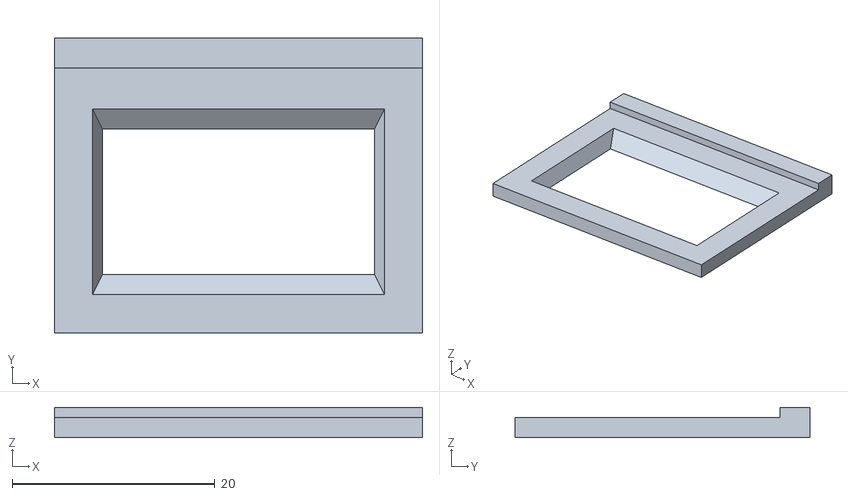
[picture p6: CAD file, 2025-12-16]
3D-Models/3btn/airtap-3btn-vent.stl
36.3 x 29.1 x 3.00

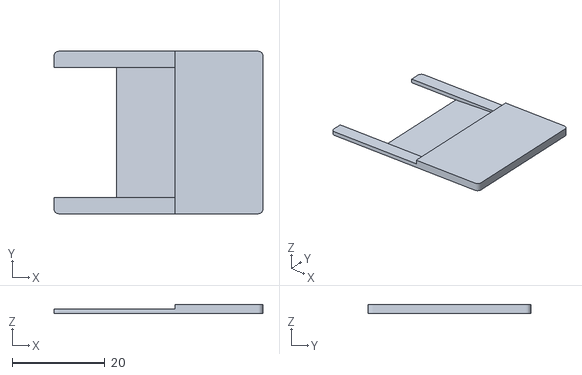
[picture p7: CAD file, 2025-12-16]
3D-Models/4btn-v1-v2/airtap-4btn-oled-bracket.stl
45.0 x 35.0 x 2.00

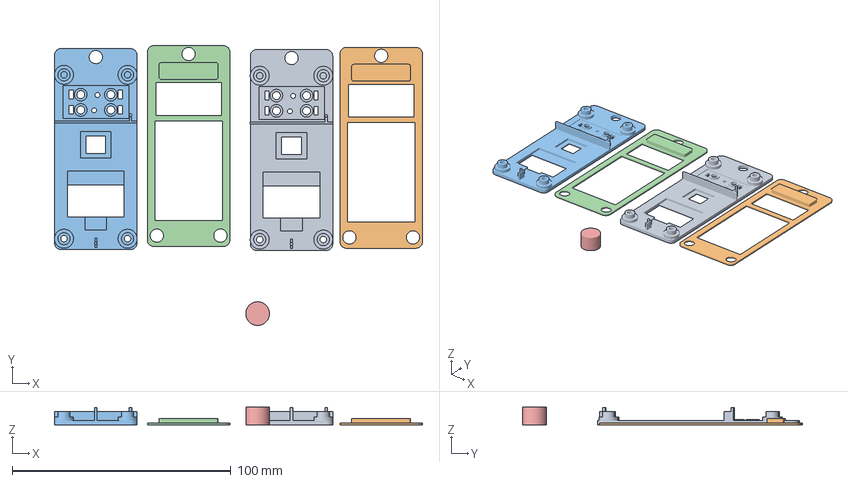
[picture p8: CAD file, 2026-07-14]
3D-Models/4btn-v3/4btn-v3-bracket.3mf
168.4 x 128.1 x 8.14 mm
4btn-v4-bracket.stl x 2
4btn-v4-bracket-2.stl x 2

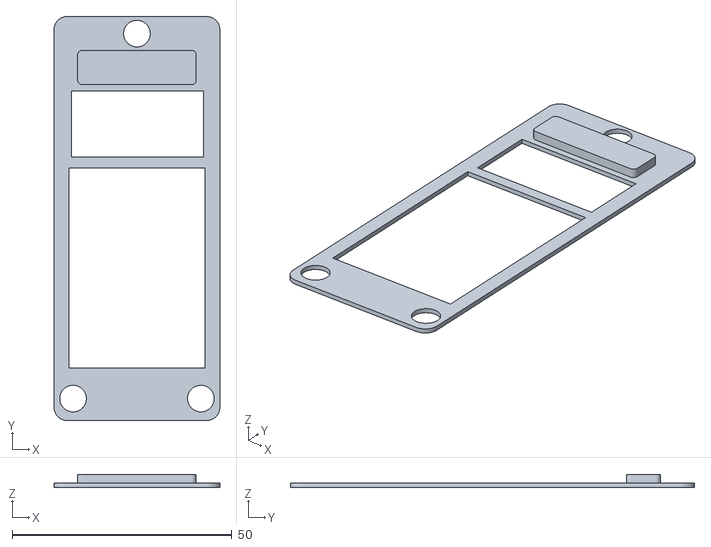
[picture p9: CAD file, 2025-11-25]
3D-Models/4btn-v3/4btn-v3-bracket-2.stl
37.8 x 92.0 x 2.98

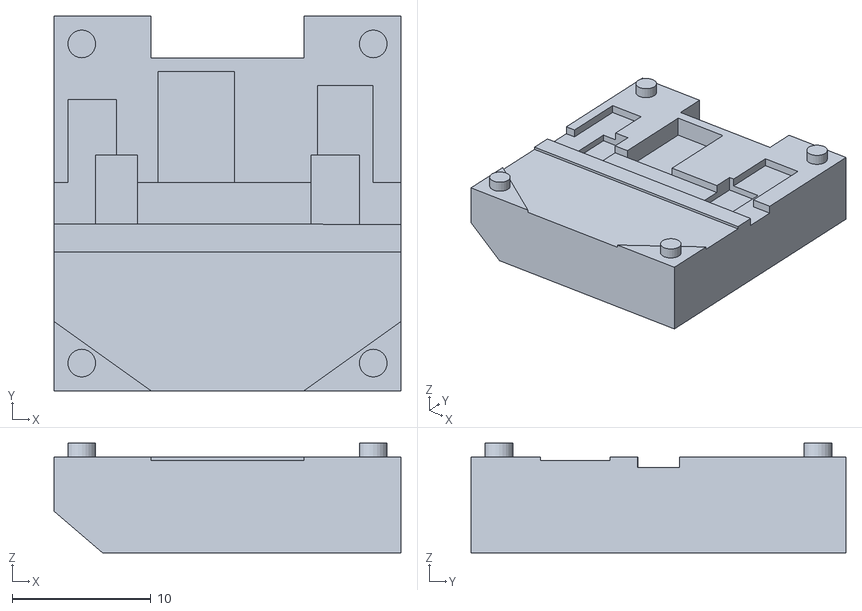
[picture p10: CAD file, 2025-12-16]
3D-Models/3btn/GME009605v4.3 Bracket airtap rev3.stl
25.0 x 27.0 x 7.90

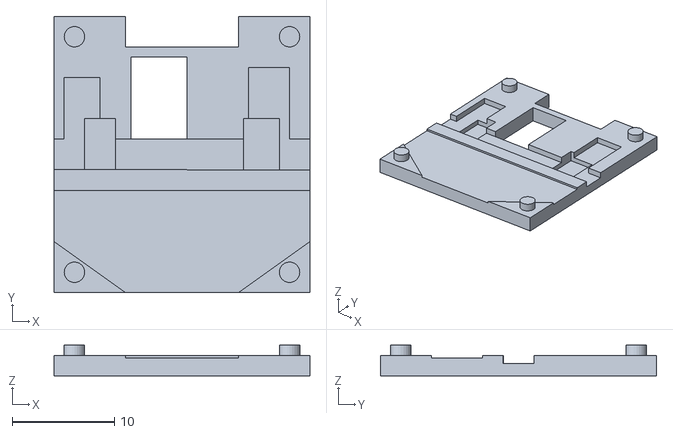
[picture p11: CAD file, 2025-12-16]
3D-Models/4btn-v1-v2/GME009605v4.3 Bracket airtap 4btn.stl
25.0 x 27.0 x 3.00

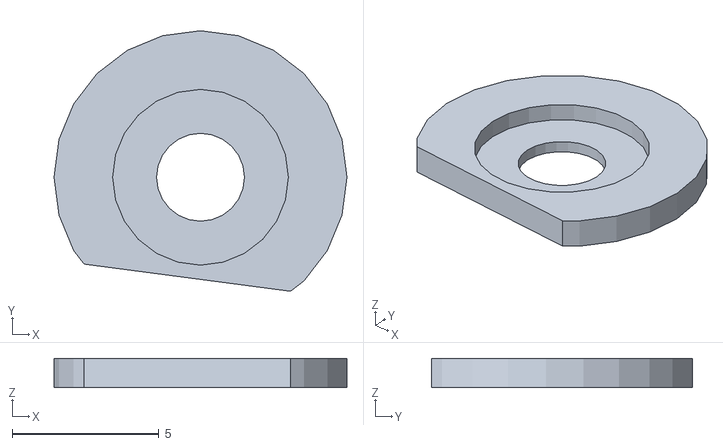
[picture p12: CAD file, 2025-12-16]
3D-Models/4btn-v3/M3 Washer x 9mm.stl
10.0 x 8.89 x 1.00

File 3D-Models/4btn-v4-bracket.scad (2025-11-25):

$fn = 25;

cornerRadius = 3;

module roundedSquare(size = [10, 10], radius = 1) {
  hull() {
    for (x = [radius, size[0] - radius])
      for (y = [radius, size[1] - radius])
        translate([x, y]) circle(r=radius);
  }
}

module roundedPlate(width, height, thickness, radius) {
  linear_extrude(thickness)
    roundedSquare([width, height], radius);
}

// 37.8mm Width x 92mm Height x 3mm Thickness

bracketWidth = 37.8;
bracketHeight = 92;
bracketThickness = 1.97;
bracketHoleDiameter = 6.1;
m3HoleDiameter = 3.3;
buttonHoleDiameter = 4.85;
oledWidth = 26;
oledHeight = 14.5;

lockingHoleWidth = 2;
lockingHoleHeight = 4;

difference() {
  roundedPlate(bracketWidth, bracketHeight, bracketThickness, cornerRadius);

  // Subtract LCD Hole
  translate([(bracketWidth - oledWidth) / 2, 15, -1]) {
    cube([oledWidth, oledHeight, bracketThickness + 2]);
  }

  //Subtract IR Hole
  translate([(bracketWidth - 9) / 2, 44, -1]) {
    cube([9, 8, bracketThickness + 2]);
  }

  //Subtract IR Hole Buffer
  translate([(bracketWidth - 14) / 2, 42, 0.75]) {
    cube([14, 12, bracketThickness + 2]);
  }

  //Subtract io header
  translate([(bracketWidth - 10) / 2, 9, 0.75]) {
    cube([10, 7, bracketThickness + 2]);
  }

  //Subtract LCD ribbon
  translate([(bracketWidth - oledWidth) / 2, 29, 0.75]) {
    cube([oledWidth, 7, bracketThickness + 2]);
  }

  //Subtract Screw holes (top)
  translate([4.35, 5, -1]) {
    cylinder(h=bracketThickness + 2, d=bracketHoleDiameter);
  }
  translate([bracketWidth - 4.35, 5, -1]) {
    cylinder(h=bracketThickness + 2, d=bracketHoleDiameter);
  }

  //Subtract Screw holes (bottom)
  translate([bracketWidth / 2, 82 + bracketHoleDiameter, -1]) {
    cylinder(h=bracketThickness + 2, d=bracketHoleDiameter);
  }

  //Button holes x4 62 then 70 from top
  translate([12, 61.5 + (buttonHoleDiameter / 2), -1]) {
    cylinder(h=bracketThickness + 2, d=buttonHoleDiameter);
  }
  translate([bracketWidth - 12, 61.5 + (buttonHoleDiameter / 2), -1]) {
    cylinder(h=bracketThickness + 2, d=buttonHoleDiameter);
  }

  translate([12, 68.5 + (buttonHoleDiameter / 2), -1]) {
    cylinder(h=bracketThickness + 2, d=buttonHoleDiameter);
  }
  translate([bracketWidth - 12, 68.5 + (buttonHoleDiameter / 2), -1]) {
    cylinder(h=bracketThickness + 2, d=buttonHoleDiameter);
  }

  //Subtract Locking Hole
  translate([6.7, 62, -1]) {
    cube([lockingHoleWidth, lockingHoleHeight, bracketThickness + 2]);
  }
  translate([bracketWidth - 8.7, 62, -1]) {
    cube([lockingHoleWidth, lockingHoleHeight, bracketThickness + 2]);
  }
  translate([6.7, 69, -1]) {
    cube([lockingHoleWidth, lockingHoleHeight, bracketThickness + 2]);
  }
  translate([bracketWidth - 8.7, 69, -1]) {
    cube([lockingHoleWidth, lockingHoleHeight, bracketThickness + 2]);
  }

  //Subtract alignment hole for locking hole
  translate([bracketWidth / 2 - 0.75, 63.75, -1]) {
    cylinder(h=bracketThickness + 2, d=2.25);
  }
  translate([bracketWidth / 2 + 0.75, 70.75, -1]) {
    cylinder(h=bracketThickness + 2, d=2.25);
  }

  //Subtract button area
  translate([4, 60, bracketThickness - 0.5]) {
    cube([30, 15, 1]);
  }
}

supportPinDiameter = 1.21;
supportPinHeight = 6;
supportPinBracketWidth = 0.93;
supportPinBracketHeight = 4.25;

//Add top support pin
translate([bracketWidth / 2, 3, 0]) {
  cylinder(h=supportPinHeight + bracketThickness, d=supportPinDiameter);
}
//Add top support bracket for pin
translate([(bracketWidth / 2) - (supportPinBracketWidth / 2), 1, 0]) {
  cube([supportPinBracketWidth, supportPinBracketHeight, supportPinBracketHeight + bracketThickness]);
}

//Add Bottom support pin
translate([bracketWidth - 3, 61 + (supportPinDiameter / 2), 0]) {
  cylinder(h=supportPinHeight + bracketThickness, d=supportPinDiameter);
}
//Add Bottom support bracket for pin
translate([bracketWidth - 3 - (supportPinBracketWidth / 2), 58, 0]) {
  cube([supportPinBracketWidth, 3, supportPinBracketHeight + bracketThickness]);
}
translate([0, 58, 0]) {
  cube([bracketWidth, supportPinBracketWidth, supportPinBracketHeight + bracketThickness]);
}

module screwBracket() {
  cylinder(h=1.7, d=8.75);
  cylinder(h=supportPinBracketHeight, d=5.6);
}

module screwBracketandHole() {
  difference() {
    screwBracket();
    translate([0, 0, -1]) {
      cylinder(h=10, d=3);
    }
  }
}
//screw mount holes
translate([4.35, 5, bracketThickness]) {
  difference() {
    screwBracketandHole();
    translate([0, 0, -1]) {
      cylinder(h=1.5, d=bracketHoleDiameter);
    }
  }
}

translate([bracketWidth - 4.35, 5, bracketThickness]) {
    difference() {
      screwBracketandHole();
      translate([0, 0, -1]) {
        cylinder(h=1.5, d=bracketHoleDiameter);
      }
    }
}

//Bottom 75 apart from top
translate([4.35, 80, bracketThickness]) {
  screwBracketandHole();
}
translate([bracketWidth - 4.35, 80, bracketThickness]) {
  screwBracketandHole();
}

buttonHoleSlider = buttonHoleDiameter + 1;
buttonHoleSliderOffsetHeight = bracketThickness - 0.5;
//Button holes x4 62 then 70 from top

translate([12, 61 + (buttonHoleSlider / 2), buttonHoleSliderOffsetHeight]) {
  difference() {
    cylinder(h=1, d=buttonHoleSlider);
    translate([0, 0, -1]) {
      cylinder(h=10, d=3.65);
    }
  }
}
translate([bracketWidth - 12, 61 + (buttonHoleSlider / 2), buttonHoleSliderOffsetHeight]) {
  difference() {
    cylinder(h=1, d=buttonHoleSlider);
    translate([0, 0, -1]) {
      cylinder(h=10, d=3.65);
    }
  }
}

translate([12, 68 + (buttonHoleSlider / 2), buttonHoleSliderOffsetHeight]) {
  difference() {
    cylinder(h=1, d=buttonHoleSlider);
    translate([0, 0, -1]) {
      cylinder(h=10, d=3.65);
    }
  }
}
translate([bracketWidth - 12, 68 + (buttonHoleSlider / 2), buttonHoleSliderOffsetHeight]) {
  difference() {
    cylinder(h=1, d=buttonHoleSlider);
    translate([0, 0, -1]) {
      cylinder(h=10, d=3.65);
    }
  }
}

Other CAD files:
3D-Models/4btn-v3/GME009605v4.3 Bracket airtap 4btn.stl
3D-Models/4btn-v3/4btn-v3-bracket-2.scad
3D-Models/4btn-v3/4btn-v3-bracket.scad
3D-Models/3btn/GME009605v4.3 Bracket airtap rev3.skp
3D-Models/3btn/airtap-3btn-vent.skp
3D-Models/4btn-v1-v2/GME009605v4.3 Bracket airtap 4btn.skp
3D-Models/4btn-v1-v2/airtap-4btn-oled-bracket.skp
3D-Models/4btn-v3/4btn-v3-bracket.stl
3D-Models/4btn-v3/GME009605v4.3 Bracket airtap 4btn.skp
3D-Models/4btn-v3/M3 Washer x 9mm.skp

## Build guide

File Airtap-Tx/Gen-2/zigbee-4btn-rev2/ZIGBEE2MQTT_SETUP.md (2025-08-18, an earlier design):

# AirTap Fan Controller - Zigbee2MQTT Setup

## Overview
This is a custom ESP32-C6 fan controller that appears as a standard Zigbee light device but controls a fan instead. It uses standard on/off and level control clusters for maximum compatibility.

## Device Features
- **On/Off Control**: Turn fan on (speed 10) or off (speed 0)
- **Speed Control**: Adjust fan speed from 0-10 using brightness control
- **Local Buttons**: Physical buttons for manual control
- **Temperature Display**: Shows current temperature on OLED
- **Zigbee Integration**: Full Zigbee2MQTT compatibility

## Zigbee2MQTT Setup

### 1. Install External Converter
Copy the `zigbee2mqtt_converter.js` file to your Zigbee2MQTT data directory:
```bash
cp zigbee2mqtt_converter.js /path/to/zigbee2mqtt/data/external_converters/
```

### 2. Restart Zigbee2MQTT
Restart your Zigbee2MQTT service to load the new converter.

### 3. Pair the Device
1. Press the **MODE** button on your AirTap device
2. The device will start pairing mode and scan for networks
3. In Zigbee2MQTT, the device should appear as "AirTap Fan Controller"

### 4. Device Control
Once paired, you can control the device via:

#### MQTT Commands
```bash
# Turn fan on (speed 10)
mosquitto_pub -h localhost -t "zigbee2mqtt/0x98a316fffe850858/set" -m '{"state": "ON"}'

# Turn fan off
mosquitto_pub -h localhost -t "zigbee2mqtt/0x98a316fffe850858/set" -m '{"state": "OFF"}'

# Set fan speed to 5 (50%)
mosquitto_pub -h localhost -t "zigbee2mqtt/0x98a316fffe850858/set" -m '{"brightness": 128}'

# Set fan speed to 7 (70%)
mosquitto_pub -h localhost -t "zigbee2mqtt/0x98a316fffe850858/set" -m '{"brightness": 179}'
```

#### Home Assistant Integration
The device will appear in Home Assistant as a light entity with:
- **On/Off Switch**: Turn fan on/off
- **Brightness Slider**: Control fan speed (0-100%)
- **Fan Speed Number**: Direct fan speed control (0-10)

## Local Controls
- **MODE Button**: Enter/exit Zigbee pairing mode
- **UP Button**: Increase fan speed
- **DOWN Button**: Decrease fan speed  
- **TOGGLE Button**: Toggle between speed 0 and 10
- **Long Press TOGGLE**: Factory reset

## Technical Details
- **Device Type**: Standard Zigbee Light (HA_ON_OFF_LIGHT_DEVICE_ID)
- **Clusters**: 
  - `genOnOff` (0x0006) - On/off control
  - `genLevelCtrl` (0x0008) - Speed control
- **Mapping**: Brightness 0-255 maps to fan speed 0-10
- **MAC Address**: `98:a3:16:ff:fe:85:08:58`

## Troubleshooting

### Device Not Found
- Ensure Zigbee2MQTT is in pairing mode
- Press MODE button on device
- Check Zigbee2MQTT logs for pairing attempts

### Fan Not Responding
- Check physical connections
- Verify PWM fan is connected to GPIO 4
- Check serial monitor for error messages

### Zigbee Connection Issues
- Press MODE button to re-enter pairing mode
- Check Zigbee2MQTT logs for connection status
- Ensure device is within range of Zigbee coordinator

## Future Improvements
- Add temperature sensor integration
- Implement fan speed feedback
- Add energy monitoring
- Support for multiple fan zones

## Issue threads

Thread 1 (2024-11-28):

Any issues with converting to the esp-idf framework and using these as bluetooth proxies?

dcgrove, 2024-11-28:
Have you tried to use this as a blue tooth proxy as well as vent controllers?

dcgrove, 2024-11-28:
I have two of the 3 button rev1 boards that I am not going to be able to use unfortunately and was looking to repurpose them. I ordered the vents and boards at the same time, but inadvertently ordered the wrong size vents. When I returned/reordered, they sent me the updated vent with the larger screen so I ordered two more of the four button boards. I haven't flashed any of the boards yet.  I was reading the docs for the bluetooth proxy and it recommends the esp-idf framework over Arduino so I though I would ask your thoughts.

ldrrp, 2024-11-28:
I stopped offering the c6 boards for now because of lack of support. The community forked platformio to add support for newer chips. Its going to be at least 3-6 months i feel like before it trickles down to esphome.

For now i recommend sticking to the arduino platformio implementation.

What happened to you is the reason i created the 4 button one. They did the same to me :(.

ldrrp, 2024-11-28:
Im planning to make a case to use these standalone withouth a vent too. Ill post those stl files here at some point. Unless you end up making one first

dcgrove, 2024-11-28:
You wouldn't happen to have a cad file or drawing of the boards would you? Would save some measuring time!

ldrrp, 2024-11-28:
I can send a step file when i get back home. Wont be till later tonight

ldrrp, 2024-11-28:
Better yet. Ill publish the step files to the repo too

dcgrove, 2024-11-28:
Awesome thanks!

dcgrove, 2024-11-28:
> Ive been using the proxy with the c3 fine

Are you using the Bluetooth proxy with the arduino framework?

ldrrp, 2024-11-29:
Yes, below is my configuration. Im using bluetooth tracking and proxy

```
esphome:
  name: bedroom-vent
  friendly_name: Bedroom Vent

esp32:
  board: esp32-c3-devkitm-1
  framework:
    type: arduino

# Enable logging
logger:
  level: WARN

# Enable Home Assistant API
api:
  encryption:
    key: ""

ota:
  - platform: esphome
    password: ""

wifi:
  ssid: !secret wifi_ssid
  password: !secret wifi_password

  # Enable fallback hotspot (captive portal) in case wifi connection fails
  ap:
    ssid: "Bedroom-Vent Fallback Hotspot"
    password: ""

captive_portal:

esp32_ble_tracker:
  scan_parameters:
    interval: 1100ms
    window: 1100ms
    active: true

bluetooth_proxy:
  active: true

i2c:
  sda: GPIO6
  scl: GPIO7
  scan: True

globals:
  - id: fan_speed
    type: int
    restore_value: yes
    initial_value: '0'

button:
  - platform: restart
    icon: mdi:power-cycle
    name: "ESP Reboot"

number:
  - platform: template
    name: "Fan Speed"
    id: fan_speed_number
    min_value: 0
    max_value: 10
    step: 1
    restore_value: true
    set_action:
      - lambda: |-
          id(fan_speed) = (int)(x);
          id(fan_speed_number).publish_state(x);

sensor:
  - platform: ntc
    sensor: temp_resistance_reading
    calibration:
      #Inversed for PTC
      - 3.389kOhm -> 0°C
      - 10.0kOhm -> 25°C
      - 27.219kOhm -> 50°C
    name: "AC Infinity Temperature"
    id: temp_sensor
    unit_of_measurement: "°C"
    accuracy_decimals: 2
    icon: "mdi:thermometer"

  - platform: resistance
    id: temp_resistance_reading
    sensor: adc_sensor
    configuration: DOWNSTREAM
    resistor: 10kOhm

  - platform: adc
    pin: GPIO4
    id: adc_sensor
    attenuation: 12db

output:
  - platform: ledc
    pin: GPIO2
    id: pwm_output_1
    frequency: 1000 Hz
    # power_supply: fan_speed

  - platform: ledc
    pin: GPIO3
    id: pwm_output_2
    frequency: 1000 Hz
    # power_supply: fan_speed

display:
  - platform: ssd1306_i2c
    model: "SSD1306 128x64"
    address: 0x3C
    # Celcius
    # lambda: |-
    #   it.printf(1, 0, id(myfont), "Airtap T4");
    #   it.printf(0, 14, id(myfont), "Temp: %.1f°C", id(temp_sensor).state);
    #   it.printf(0, 28, id(myfont), "Fan Speed: %d", id(fan_speed));
    # Fahrenheit
    lambda: |-
      it.printf(1, 0, id(myfont), "Airtap T4");
      float temp_f = (id(temp_sensor).state * 9.0 / 5.0) + 32.0;
      it.printf(0, 14, id(myfont), "Temp: %.1f°F", temp_f);
      it.printf(0, 28, id(myfont), "Fan Speed: %d", id(fan_speed));

font:
  - file: "fonts/Arial.ttf"
    id: myfont
    size: 12

binary_sensor:
  - platform: gpio
    pin: GPIO10
    name: "Mode Button"
    on_press:
      then:
        - lambda: |-
            if (id(fan_speed) == 0) {
              id(fan_speed) = 10;
            } else {
              id(fan_speed) = 0;
            }
            id(fan_speed_number).publish_state(id(fan_speed)); // Publish updated state

  - platform: gpio
    pin: GPIO8
    name: "Up Button"
    on_press:
      then:
        - lambda: |-
            if (id(fan_speed) < 10){
              id(fan_speed) += 1;
              id(fan_speed_number).publish_state(id(fan_speed)); // Publish updated state
            }

  - platform: gpio
    pin: GPIO9
    name: "Down Button"
    on_press:
      then:
        - lambda: |-
            if (id(fan_speed) > 0){
              id(fan_speed) -= 1;
              id(fan_speed_number).publish_state(id(fan_speed)); // Publish updated state
            }

light:
  - platform: monochromatic
    output: pwm_output_1
    name: "Fan 1 Speed"
    id: fan_1
    internal: true  # Hide this from Home Assistant

  - platform: monochromatic
    output: pwm_output_2
    name: "Fan 2 Speed"
    id: fan_2
    internal: true  # Hide this from Home Assistant

interval:
  - interval: 1s
    then:
      - light.turn_on:
          id: fan_1
          brightness: !lambda |-
            if (id(fan_speed) == 0) {
              return 0.0;
            } else if (id(fan_speed) == 1) {
              return 0.38;  // Minimum value to start the fan
            } else {
              return (id(fan_speed) + 3) / 13.0;
            }
      - light.turn_on:
          id: fan_2
          brightness: !lambda |-
            if (id(fan_speed) == 0) {
              return 0.0;
            } else if (id(fan_speed) == 1) {
              return 0.38;  // Minimum value to start the fan
            } else {
              return (id(fan_speed) + 3) / 13.0;
            }
```

ldrrp, 2024-11-29:
> You wouldn't happen to have a cad file or drawing of the boards would you? Would save some measuring time!

Just exported the OBJ file for use in 3d software. Note that some components might be missing since i solder them on after they are made.

ldrrp, 2024-12-05:
@dcgrove can i close this? Also made a ticket for the case #3

dcgrove, 2024-12-05:
Thanks for all the help! The vents are working great now!

Closed 2024-12-05.

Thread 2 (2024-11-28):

Trouble Flashing second device

dcgrove, 2024-11-28:
Hello, I just attempted to flash my second device using the stock yaml file included below and am showing these errors in the logs after booting up. I have tried refreshing via USB and OTA with no success. Any ideas?

`esphome:
  name: left-vent
  friendly_name: Left Vent

esp32:
  board: esp32-c3-devkitm-1
  framework:
    type: arduino

# Enable logging
logger:

# Enable Home Assistant API
api:
  encryption:
    key: "*****"

ota:
  - platform: esphome
    password: "******"

wifi:
  ssid: !secret wifi_ssid
  password: !secret wifi_password

  # Enable fallback hotspot (captive portaal) in case wifi connection fails
  ap:
    ssid: "Left-Vent Fallback Hotspot"
    password: "Ud9NoeR7PvVU"

captive_portal:

i2c:
  sda: GPIO6
  scl: GPIO7
  scan: True

globals:
  - id: fan_speed
    type: int
    restore_value: yes
    initial_value: '0'

button:
  - platform: restart
    icon: mdi:power-cycle
    name: “ESP Reboot”

number:
  - platform: template
    name: "Fan Speed"
    id: fan_speed_number
    min_value: 0
    max_value: 10
    step: 1
    restore_value: true
    set_action:
      - lambda: |-
          id(fan_speed) = (int)(x);
          id(fan_speed_number).publish_state(x);

sensor:
  - platform: ntc
    sensor: temp_resistance_reading
    calibration:
      #Inversed for PTC
      - 3.389kOhm -> 0°C
      - 10.0kOhm -> 25°C
      - 27.219kOhm -> 50°C
      # - 10.0kOhm -> 28.88°C
      # # - 10.86kOhm -> 23.55°C
      # - 13kOhm -> 16.94°C
      # - 17kOhm -> 9.44°C

    name: "AC Infinity Temperature"
    id: temp_sensor
    unit_of_measurement: "°C"
    accuracy_decimals: 2
    icon: "mdi:thermometer"

  - platform: resistance
    id: temp_resistance_reading
    sensor: adc_sensor
    configuration: DOWNSTREAM
    resistor: 10kOhm

  - platform: adc
    pin: GPIO4
    id: adc_sensor
    attenuation: 12db

output:
  - platform: ledc
    pin: GPIO2
    id: pwm_output_1
    frequency: 1000 Hz
    # power_supply: fan_speed

display:
  - platform: ssd1306_i2c
    model: "SSD1306 128x64"
    address: 0x3C
    # Celcius
    # lambda: |-
    #   it.printf(1, 0, id(myfont), "Airtap T-Series");
    #   it.printf(0, 14, id(myfont), "Temp: %.1f°C", id(temp_sensor).state);
    #   it.printf(0, 28, id(myfont), "Fan Speed: %d", id(fan_speed));
    # Fahrenheit
    lambda: |-
      it.printf(1, 0, id(myfont), "Airtap T-Series");
      float temp_f = (id(temp_sensor).state * 9.0 / 5.0) + 32.0;
      it.printf(0, 14, id(myfont), "Temp: %.1f°F", temp_f);
      it.printf(0, 28, id(myfont), "Fan Speed: %d", id(fan_speed));

# You will need to download the font file available online and place it in the same directory as your configuration file
# https://font.download/font/arial
font:
  - file: "fonts/Arial.ttf"
    id: myfont
    size: 12

binary_sensor:
  - platform: gpio
    pin: GPIO10
    name: "Mode Button"
    on_press:
      then:
        - lambda: |-
            if (id(fan_speed) == 0) {
              id(fan_speed) = 10;
            } else {
              id(fan_speed) = 0;
            }
            id(fan_speed_number).publish_state(id(fan_speed)); // Publish updated state

  - platform: gpio
    pin: GPIO20
    name: "Up Button"
    on_press:
      then:
        - lambda: |-
            if (id(fan_speed) < 10){
              id(fan_speed) += 1;
              id(fan_speed_number).publish_state(id(fan_speed)); // Publish updated state
            }

  - platform: gpio
    pin: GPIO8
    name: "Down Button"
    on_press:
      then:
        - lambda: |-
            if (id(fan_speed) > 0){
              id(fan_speed) -= 1;
              id(fan_speed_number).publish_state(id(fan_speed)); // Publish updated state
            }

  - platform: gpio
    pin: GPIO9
    name: "Toggle Button"
    on_press:
      then:
        - lambda: |-
            if (id(fan_speed) == 0) {
              id(fan_speed) = 10;
            } else {
              id(fan_speed) = 0;
            }
            id(fan_speed_number).publish_state(id(fan_speed)); // Publish updated state

light:
  - platform: monochromatic
    output: pwm_output_1
    name: "Fan 1 Speed"
    id: fan_1
    internal: true  # Hide this from Home Assistant

interval:
  - interval: 1s
    then:
      - light.turn_on:
          id: fan_1
          brightness: !lambda |-
            if (id(fan_speed) == 0) {
              return 0.0;
            } else if (id(fan_speed) == 1) {
              return 0.38;  // Minimum value to start the fan
            } else {
              return (id(fan_speed) + 4) / 14.0;
            }    `

`[11:06:58][I][logger:171]: Log initialized
[11:06:58][C][safe_mod[I][logger:171]: Log initialized
[11:06:58][C][safe_mode:079]: There have been 8 suspected unsuccessful boot attempts
[11:06:58][D][esp32.preferences:114]: Saving 1 preferences to flash...
[11:07:00][D][esp32.preferences:143]: Saving 1 prefereE (5237) task_wdt: Task watchdog got triggered. The following tasks did not reset the watchdog in time:
[11:07:00]E (5237) task_wdt:  - loopTask (CPU 0)
[11:07:00]E (5237) task_wdt: Tasks currently running:
[11:07:00]E (5237) task_wdt: CPU 0: IDLE
[11:07:00]E (5237) task_wdt: Aborting.
[11:07:00]ESP-ROM:esp32c3-api1-20210207
[11:07:00]Build:Feb  7 2021
[11:07:00]rst:0x3 (RTC_SW_SYS_RST),boot:0xd (SPI_FAST_FLASH_BOOT)
[11:07:00]Saved PC:0x403825fa
[11:07:00]SPIWP:0xee
[11:07:00]mode:DIO, clock div:1
[11:07:00]load:0x3fcd6100,len:0x438
[11:07:00]load:0x403ce000,len:0x918
[11:07:00]load:0x403d0000,len:0x24e4
[11:07:00]entry 0x403ce000
[11:07:00][I][logger:171]: Log initialized
[11:07:00][C][safe_mode:079]: There have been 9 suspected unsuccessful boot attempts
[11:07:00][D][esp32.preferences:114]: Saving 1 preferences to flash...
[11:07:00][D][esp32.preferences:143]: Saving 1 preferences to flash: 0 cached, 1 written, 0 failed
[11:07:00][I][app:029]: Running through setup()...
[11:07:00][I][i2c.arduino:218]: Performing I2C bus recovery
[11:07:00][E][i2c.arduino:291]: Recovery failed: SDA is held LOW after clock pulse cycle
[11:07:05]E (5226) task_wdt: Task watchdog got triggered. The following tasks did not reset the watchdog in time:
[11:07:05]E (5226) task_wdt:  - loopTask (CPU 0)
[11:07:05]E (5226) task_wdt: Tasks currently running:
[11:07:05]E (5226) task_wdt: CPU 0: IDLE
[11:07:05]E (5226) task_wdt: Aborting.
[11:07:06]ESP-ROM:esp32c3-api1-20210207
[11:07:06]Build:Feb  7 2021
[11:07:06]rst:0x3 (RTC_SW_SYS_RST),boot:0xd (SPI_FAST_FLASH_BOOT)
[11:07:06]Saved PC:0x403825fa
[11:07:06]SPIWP:0xee
[11:07:06]mode:DIO, clock div:1
[11:07:06]load:0x3fcd6100,len:0x438
[11:07:06]load:0x403ce000,len:0x918
[11:07:06]load:0x403d0000,len:0x24e4
[11:07:06]entry 0x403ce000
[11:07:06][I][logger:171]: Log initialized
[11:07:06][C][safe_mode:079]: There have been 10 suspected unsuccessful boot attempts
[11:07:06][D][esp32.preferences:114]: Saving 1 preferences to flash...
[11:07:06][D][esp32.preferences:143]: Saving 1 preferences to flash: 0 cached, 1 written, 0 failed
[11:07:06][E][safe_mode:086]: Boot loop detected. Proceeding to safe mode
[11:07:06][E][component:164]: Component safe_mode set Error flag: unspecified
[11:07:06][I][app:029]: Running through setup()...
[11:07:06][C][wifi:048]: Setting up WiFi...
[11:07:06][C][wifi:061]: Starting WiFi...
[11:07:06][C][wifi:062]:   Local MAC: 24:EC:4A:C9:90:74
[11:07:06][D][wifi:482]: Starting scan...
[11:07:06][W][component:157]: Component wifi set Warning flag: scanning for networks
[11:07:08][D][wifi:497]: Found networks:
[11:07:08][I][wifi:541]: - 'nest' (A6:05:D6:D7:34:C9) [redacted]▂▄▆█
[11:07:08][D][wifi:542]:     Channel: 6
[11:07:08][D][wifi:543]:     RSSI: -52 dB
[11:07:08][I][wifi:541]: - 'nest' (A2:05:D6:5B:42:C6) [redacted]▂▄▆█
[11:07:08][D][wifi:542]:     Channel: 1
[11:07:08][D][wifi:543]:     RSSI: -67 dB
[11:07:08][I][wifi:541]: - 'nest' (F2:63:DA:74:2D:3A) [redacted]▂▄▆█
[11:07:08][D][wifi:542]:     Channel: 1
[11:07:08][D][wifi:543]:     RSSI: -69 dB
[11:07:08][D][wifi:546]: - 'prettyfly4awifi'[redacted] (9C:05:D6:D7:34:C9) [redacted]▂▄▆█
[11:07:08][D][wifi:546]: - 'daddyisawesome'[redacted] (AA:05:D6:D7:34:C9) [redacted]▂▄▆█
[11:07:08][D][wifi:546]: - ''[redacted] (AE:05:D6:D7:34:C9) [redacted]▂▄▆█
[11:07:08][D][wifi:546]: - 'prettyfly4awifi'[redacted] (9C:05:D6:5B:42:C6) [redacted]▂▄▆█
[11:07:08][D][wifi:546]: - 'daddyisawesome'[redacted] (A6:05:D6:5B:42:C6) [redacted]▂▄▆█
[11:07:08][D][wifi:546]: - ''[redacted] (AA:05:D6:5B:42:C6) [redacted]▂▄▆█
[11:07:08][D][wifi:546]: - 'daddyisawesome'[redacted] (EA:63:DA:74:2D:3A) [redacted]▂▄▆█
[11:07:08][D][wifi:546]: - 'test'[redacted] (E6:63:DA:74:2D:3A) [redacted]▂▄▆█
[11:07:08][D][wifi:546]: - 'prettyfly4awifi'[redacted] (EE:63:DA:74:2D:3A) [redacted]▂▄▆█
[11:07:08][D][wifi:546]: - ''[redacted] (E0:63:DA:74:2D:3A) [redacted]▂▄▆█
[11:07:08][D][wifi:546]: - ''[redacted] (FA:D2:AC:B2:1C:4F) [redacted]▂▄▆█
[11:07:08][D][wifi:546]: - 'CrawHome'[redacted] (FA:D2:AC:B2:1C:4C) [redacted]▂▄▆█
[11:07:08][D][wifi:546]: - ''[redacted] (FA:D2:AC:B2:1C:4A) [redacted]▂▄▆█
[11:07:08][D][wifi:546]: - ''[redacted] (FA:D2:AC:B2:1C:4D) [redacted]▂▄▆█
[11:07:08][I][wifi:313]: WiFi Connecting to 'nest'...
[11:07:08][W][wifi_esp32:545][arduino_events]: Event: Disconnected ssid='nest' bssid=A6:05:D6:D7:34:C9[redacted] reason='Authentication Failed'
[11:07:08][W][wifi:674]: WiFi Unknown connection status 0
[11:07:08][I][wifi:313]: WiFi Connecting to 'nest'...
[11:07:09][W][wifi_esp32:545][arduino_events]: Event: Disconnected ssid='nest' bssid=A6:05:D6:D7:34:C9[redacted] reason='Auth Expired'
[11:07:09][W][wifi:653]: Error while connecting to network.
[11:07:09][D][wifi:697]: Retrying with hidden networks...
[11:07:14][I][wifi:313]: WiFi Connecting to 'nest'...
[11:07:17][I][wifi:617]: WiFi Connected!
[11:07:17][C][wifi:428]:   Local MAC: 24:EC:4A:C9:90:74
[11:07:17][C][wifi:433]:   SSID: 'nest'[redacted]
[11:07:17][C][wifi:436]:   IP Address: 192.168.1.181
[11:07:17][C][wifi:440]:   BSSID: A6:05:D6:D7:34:C9[redacted]
[11:07:17][C][wifi:441]:   Hostname: 'left-vent'
[11:07:17][C][wifi:443]:   Signal strength: -50 dB ▂▄▆█
[11:07:17][C][wifi:447]:   Channel: 6
[11:07:17][C][wifi:448]:   Subnet: 255.255.255.0
[11:07:17][C][wifi:449]:   Gateway: 192.168.1.1
[11:07:17][C][wifi:450]:   DNS1: 192.168.1.36
[11:07:17][C][wifi:451]:   DNS2: 192.168.1.148
[11:07:17][D][wifi:626]: Disabling AP...
[11:07:17][I][app:062]: setup() finished successfully!
[11:07:17][W][safe_mode:099]: SAFE MODE IS ACTIVE
[11:07:17][W][component:170]: Component wifi cleared Warning flag
[11:07:17][I][app:100]: ESPHome version 2024.11.2 compiled on Nov 28 2024, 11:04:47
[11:07:17][C][wifi:600]: WiFi:
[11:07:17][C][wifi:428]:   Local MAC: 24:EC:4A:C9:90:74
[11:07:17][C][wifi:433]:   SSID: 'nest'[redacted]
[11:07:17][C][wifi:436]:   IP Address: 192.168.1.181
[11:07:17][C][wifi:440]:   BSSID: A6:05:D6:D7:34:C9[redacted]
[11:07:17][C][wifi:441]:   Hostname: 'left-vent'
[11:07:17][C][wifi:443]:   Signal strength: -50 dB ▂▄▆█
[11:07:17][C][wifi:447]:   Channel: 6
[11:07:17][C][wifi:448]:   Subnet: 255.255.255.0
[11:07:17][C][wifi:449]:   Gateway: 192.168.1.1
[11:07:17][C][wifi:450]:   DNS1: 192.168.1.36
[11:07:17][C][wifi:451]:   DNS2: 192.168.1.148
[11:07:17][C][logger:185]: Logger:
[11:07:17][C][logger:186]:   Level: DEBUG
[11:07:17][C][logger:188]:   Log Baud Rate: 115200
[11:07:17][C][logger:189]:   Hardware UART: USB_CDC
[11:07:17][C][captive_portal:089]: Captive Portal:
[11:07:17][C][mdns:116]: mDNS:
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
ldrrp, 2024-11-29:
What are you using to power the device. Looks like the OLED is not responding and possibly being underpowered. When the device is powered by the 12v vent supply does the screen power on?

The error i notice is i2c bus error which has to do with the OLED.

dcgrove, 2024-11-29:
The two middle pins on the OLED were not soldered. A little dab of solder fixed it right up.

ldrrp, 2024-11-29:
So sorry about that. Ill step up my game.

dcgrove, 2024-11-29:
No worries, it was an easy fix.

Closed 2024-11-29.

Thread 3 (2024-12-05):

3D Case for Gen1 3 button

ldrrp, 2024-12-05:
create case for reuseable pcb of gen1 3 button boards. A few users have already been burned by amazons airtap listing showing incorrect images. Lets make a case to reuse the older boards. I also have several of the older gen 1 in stock sitting around that can be reused.

I have uploaded the pcb step files for easier modeling.

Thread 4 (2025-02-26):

Airtap T4 Gen 1: Submit to esphome

ldrrp, 2025-02-26:
Submit this to esphome using esp32-dikale as refference

ldrrp, 2025-03-02:
[https://github.com/esphome/esphome-devices/pull/1038](https://github.com/esphome/esphome-devices/pull/1038)

ldrrp, 2025-03-05:
https://github.com/esphome/esphome-devices/pull/1040

ldrrp, 2025-03-15:
This is complete

Closed 2025-03-15.

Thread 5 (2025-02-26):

Airtap T4 Gen 2 Submit to esphome

ldrrp, 2025-02-26:
Submit this to esphome using esp32-dikale as reference

ldrrp, 2025-03-05:
https://github.com/esphome/esphome-devices/pull/1041

ldrrp, 2025-03-15:
completed

Closed 2025-03-15.

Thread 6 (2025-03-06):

Disable Control panel

ldrrp, 2025-03-06:
Add a toggle in home assistant that lets the user disable the panels buttons. This will prevent unauthorized users from tampering with the settings directly.

must restore state, must default to enabled

ldrrp, 2025-03-06:
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

Closed 2025-03-06.

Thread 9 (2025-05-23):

Airtap fan modes

ldrrp, 2025-05-23:
Built in fan modes like our dikale devices. Heat mode, cool mode and temp ranges. Or just manual mode

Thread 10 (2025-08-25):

ESP32C6 Models RF Switch

ldrrp, 2025-08-25:
Write and test functions for RF switching the esp32c6 antenna. Some logic i had chatgpt write up but its untested and unvalidated

```
# --- Antenna selection (ESP32-C6, fixed pins) -------------------------------

# Control pins for the RF path
output:
  - platform: gpio
    id: rf_select
    pin: GPIO3
    # inverted: true   # uncomment if RF switch logic is inverted

  - platform: gpio
    id: ext_antenna_power
    pin: GPIO14
    # inverted: true   # uncomment if needed

# User-facing toggle that PERSISTS the choice across reboots
switch:
  - platform: template
    id: wifi_antenna_external
    name: "Wi-Fi Antenna: External"
    icon: mdi:antenna
    restore_state: true
    optimistic: true

    turn_on_action:
      - script.execute: apply_external_antenna

    turn_off_action:
      - script.execute: apply_internal_antenna

# Ensure the selected antenna is applied before Wi-Fi comes up
on_boot:
  priority: 800
  then:
    - if:
        condition:
          switch.is_on: wifi_antenna_external
        then:
          - script.execute: apply_external_antenna
        else:
          - script.execute: apply_internal_antenna

# Implementation details — safely switch by cycling Wi-Fi
script:
  - id: apply_external_antenna
    mode: restart
    then:
      - wifi.disable
      - delay: 200ms
      - output.turn_on: ext_antenna_power
      - output.turn_on: rf_select
      - delay: 200ms
      - wifi.enable

  - id: apply_internal_antenna
    mode: restart
    then:
      - wifi.disable
      - delay: 200ms
      - output.turn_off: rf_select
      - output.turn_off: ext_antenna_power
      - delay: 200ms
      - wifi.enable

```

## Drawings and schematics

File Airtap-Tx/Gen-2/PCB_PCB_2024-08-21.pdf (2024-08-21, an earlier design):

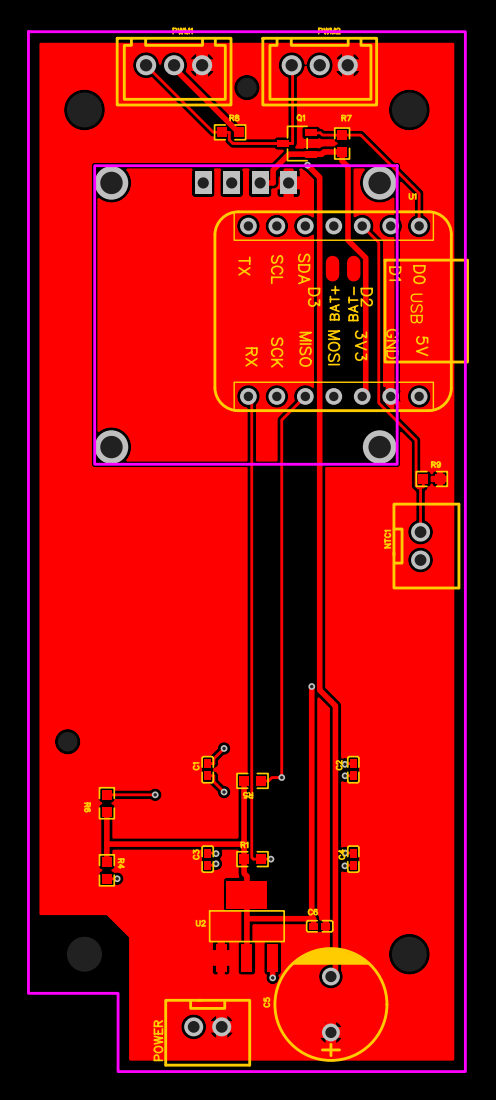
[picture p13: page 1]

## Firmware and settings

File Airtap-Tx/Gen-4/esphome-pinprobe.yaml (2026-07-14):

# Gen-4 OEM pin confirmation firmware (ESP32-C6)
# Cycles candidate pins with distinct patterns + serial logs.
#
# WARNING: OEM boards have Secure Boot + Flash Encryption enabled.
# Unsigned images will not boot on the production Airtap. Use this on an
# unlocked ESP32-C6-WROOM-1, or keep oem-firmware-full.bin ready to restore.
#
# Candidates under test:
#   GPIO0  - LEDC 25 kHz PWM  (fan PWM / Q5?)
#   GPIO1  - 2 kHz beep bursts (piezo?)
#   GPIO4  - 4 kHz beep bursts (piezo alt?)
#   GPIO20 - slow 1 Hz blink   (backlight?)
#   GPIO3  - slow blink        (unknown leftover)
#   GPIO12 - slow blink        (unknown leftover)

substitutions:
  name: "airtap-gen4-pinprobe"
  friendly_name: "AirTap Gen4 PinProbe"

esphome:
  name: "${name}"
  friendly_name: "${friendly_name}"
  on_boot:
    priority: 600
    then:
      - logger.log: "========================================"
      - logger.log: " Gen-4 pinprobe booted"
      - logger.log: " GPIO0=PWM25k  GPIO1=2kHz  GPIO4=4kHz"
      - logger.log: " GPIO20=1Hz    GPIO3=1Hz   GPIO12=1Hz"
      - logger.log: "========================================"

esp32:
  board: esp32-c6-devkitc-1
  variant: ESP32C6
  framework:
    type: esp-idf

logger:
  level: INFO
  baud_rate: 115200

# Minimal network so ESPHome still builds; not required for probing.
wifi:
  ap:
    ssid: "Gen4-PinProbe"
    password: "pinprobe1"
  min_auth_mode: WPA2

captive_portal:

output:
  - platform: ledc
    id: out_pwm0
    pin: GPIO0
    frequency: 25000 Hz

  - platform: ledc
    id: out_beep1
    pin: GPIO1
    frequency: 2000 Hz

  - platform: ledc
    id: out_beep4
    pin: GPIO4
    frequency: 4000 Hz

  - platform: gpio
    id: out_io20
    pin: GPIO20

  - platform: gpio
    id: out_io3
    pin: GPIO3

  - platform: gpio
    id: out_io12
    pin: GPIO12

globals:
  - id: phase
    type: int
    restore_value: no
    initial_value: "0"

interval:
  - interval: 3s
    then:
      - lambda: |-
          id(phase) = (id(phase) + 1) % 6;
          int p = id(phase);
          // Idle all outputs first
          id(out_pwm0).set_level(0.0f);
          id(out_beep1).set_level(0.0f);
          id(out_beep4).set_level(0.0f);
          id(out_io20).turn_off();
          id(out_io3).turn_off();
          id(out_io12).turn_off();

          if (p == 0) {
            ESP_LOGI("pinprobe", "PHASE0 GPIO0 PWM 25kHz @ 50%% (fan?)");
            id(out_pwm0).set_level(0.50f);
          } else if (p == 1) {
            ESP_LOGI("pinprobe", "PHASE1 GPIO1 2kHz @ 50%% (piezo?)");
            id(out_beep1).set_level(0.50f);
          } else if (p == 2) {
            ESP_LOGI("pinprobe", "PHASE2 GPIO4 4kHz @ 50%% (piezo alt?)");
            id(out_beep4).set_level(0.50f);
          } else if (p == 3) {
            ESP_LOGI("pinprobe", "PHASE3 GPIO20 ON (backlight?)");
            id(out_io20).turn_on();
          } else if (p == 4) {
            ESP_LOGI("pinprobe", "PHASE4 GPIO3 ON (unknown)");
            id(out_io3).turn_on();
          } else {
            ESP_LOGI("pinprobe", "PHASE5 GPIO12 ON (unknown)");
            id(out_io12).turn_on();
          }

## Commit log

2024-08-24 updated gen2 button mapping
2025-03-05 Add missing ids and improve to conform with esphome requirements
    [esphome-3btn-rev2.yaml, esphome-4btn-rev1.yaml]
2025-03-06 Disable panel buttons feature
2025-04-13 ignore strapping errors
2025-07-28 Switched to ESP-IDF
2025-08-18 Zigbee test firmware
    [partitions.csv]
2025-08-18 Pairing to network is working zigbee
    [partitions.csv]
2025-08-30 Rename zigbee-4btn-rev3 to zigbee-4btn-rev2 and fix submodule path
    [partitions.csv]
2025-08-30 Split up led and fan control, inverse led
2025-11-25 Docs, bracket
    [4btn-v4-bracket-2.scad, 4btn-v4-bracket-2.stl, 4btn-v4-bracket.3mf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]
2025-12-16 Fix 3btn gen3 firmware, 3d models
    [4btn-v3-bracket-2.scad, 4btn-v3-bracket-2.stl, 4btn-v3-bracket.3mf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]
2026-07-14 Gen 4 notes
    [4btn-v3-bracket.3mf]

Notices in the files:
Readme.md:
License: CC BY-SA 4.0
